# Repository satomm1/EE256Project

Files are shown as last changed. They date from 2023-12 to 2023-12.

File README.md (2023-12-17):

# EE 256 Project --- The Smart Pot
Matthew Sato <br />
satomm@stanford.edu <br />
Autumn 2023

This repository contains three folders: [`electrical`](electrical), [`software`](software), and [`docs`](docs) which contain all the project deliverables for this project. The project summary with my perspectives on this project is located at the [bottom of this page](#project-summary).

## The Smart Pot
The smart pot is designed as a completely autonomous plant pot that gives you the ability to be a plant parent without the trouble of remembering to water it on a regular basis. It gives water to the plant when it actually is thirsty. Now you can travel without being worried about watering your plant!

### Features of the Smart Pot
- Senses the ambient air temperature and soil moisture of the plant
- Automatically pumps water into pot when soil moisture drops too low
- Sensor to indicate when the water reservoir is low
- Display to show the temperature
- Ability to change temperature units, activate pump manually, and change the threshold at which the pump is activated
- Serial desktop interface and web-based HTML interface
- The features are fully integrated across the board, serial interface, and webpage. Any update in setting in one of these interfaces results in the corresponding update to the other interfaces.


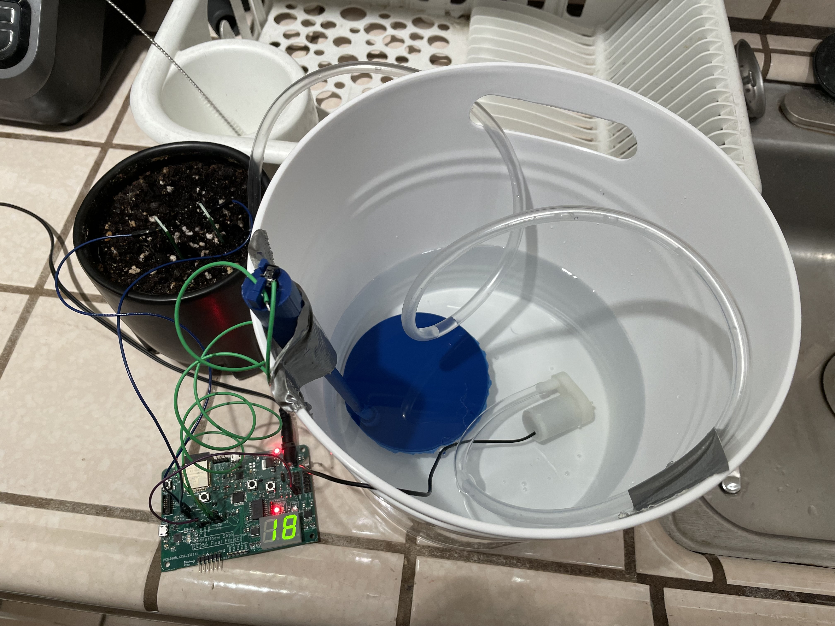
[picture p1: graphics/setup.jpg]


### Implementation Details of the Smart Pot
- The Smart Pot is built on a PCB and is under the control of a PIC32 microcontroller
- Temperature sensing is performed via a thermistor
- Soil moisture sensing is performed with two probes manufuctured on a PCB
- The water tank sensor is a limit switch which is activated by a plunger when the water is too low
- The WiFi capability is added with an ESP32 and communicates with the PIC32 via SPI
- Powered with a 5 V DC barrel jack
- A 7 segment display implemented with shift registers and SPI
- 2x UART to USB bridges to allow serial communication with a desktop machine

### More Details
To learn more about the product, visit the following folders:
1. [`docs`](docs/): contains the product brief, product requirements, product design document, bill of materials, bringup plan, and unit tests document
2. [`electrical`](electrical/): contains the detailed KiCad schematic and PCB layout
3. [`software`](software/): contains the software for the Smart Pot

### Instruction Manual
The fully functional board appears as follows:
The unit with components labeled

A. The power supply barrel jack. Insert 5V DC only. <br />
B. The display for the product. Can show temperature in F/C, or the soil moisture percentage <br />
C. The function button. Short pressing once will switch the watering frequency to between the low threshold and the high threshold. A long press will activate the pump. A double press activates selection mode. In selection mode, you can click the button to select Fahrenheit units, Celsius Units, or Soil Moisture to display. After 5 seconds of inactivity in selection mode, the display will show the desired quantity.<br />
D. The serial output. Connect this USB-Micro port to your computer and see the current data using a baud rate of 115200. I recommend TeraTerm, and the proper driver for a CP2102 USB-UART driver must be installed on your machine. The output looks like the following:
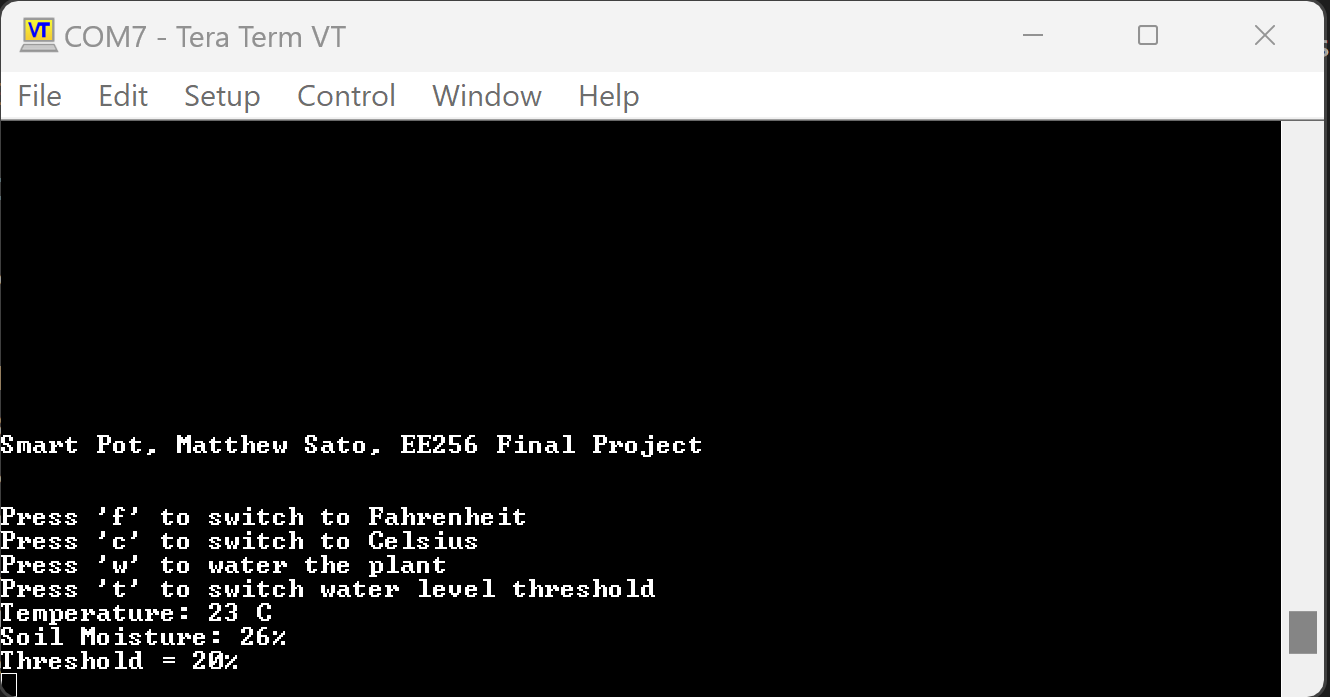
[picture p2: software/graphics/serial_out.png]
An image of the serial out interface

E. These two LEDs indicate if the low soil moisture threshold or high soil moisture threshold are selected.<br />
F. This blue LED indicates when your water tank is low:

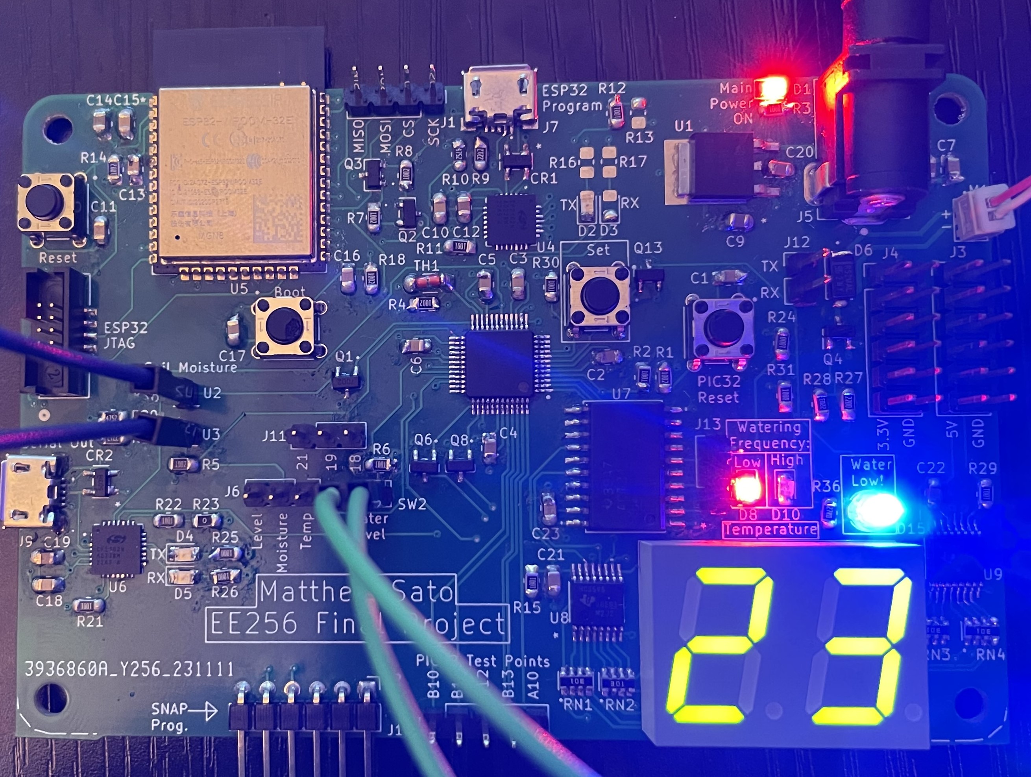
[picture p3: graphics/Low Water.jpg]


G. The port for the pump<br />
H. The ports for the soil moisture probes. The probes should be placed in the pot approximately one inch apart:

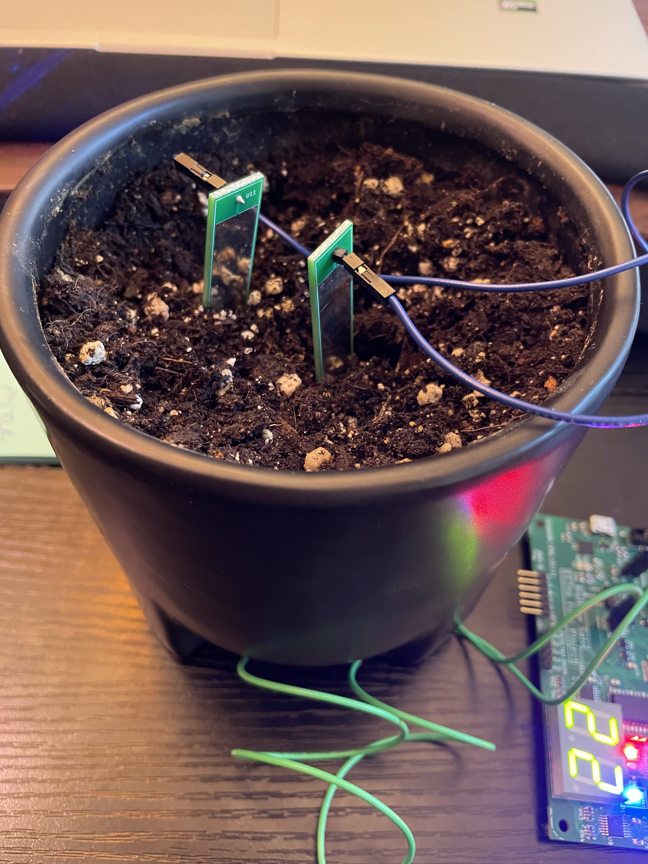
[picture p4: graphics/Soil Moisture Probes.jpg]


I. The ports for the water tank level sensor. The sensor can be mounted as follows:

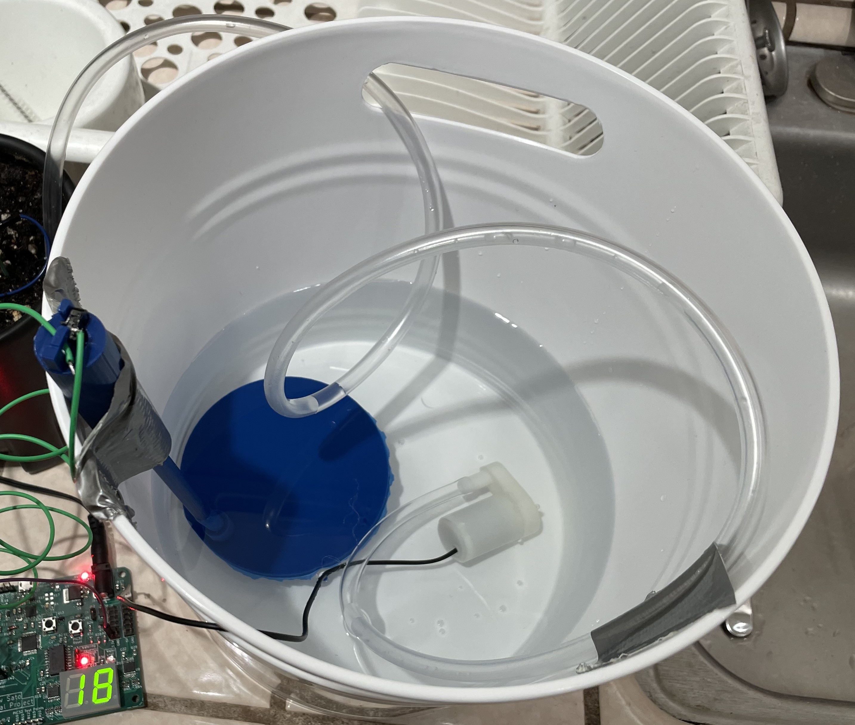
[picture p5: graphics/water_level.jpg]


The unit should be turned on for approximately 5 minutes before a reliable temperature can be maintained.

All data can also be viewed on a web browser:
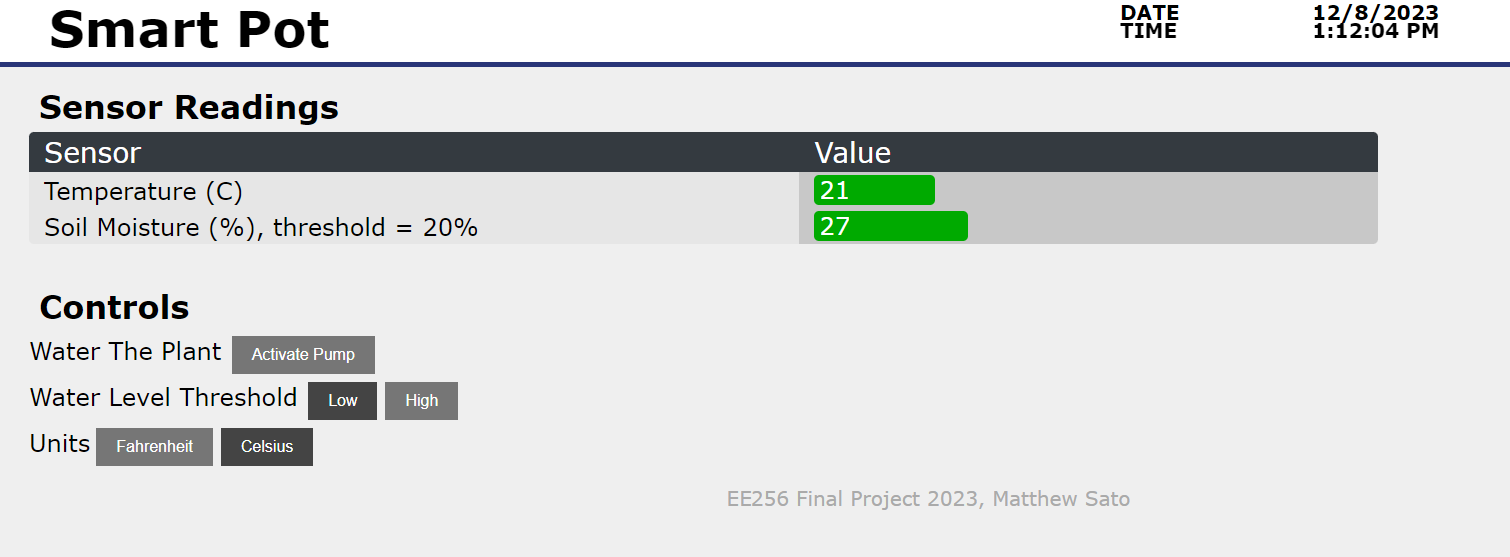
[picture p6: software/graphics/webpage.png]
An image of the webpage


# Project Summary
- In retrospect, why you found this project compelling and was the scope of the project comfortable.
    - I liked that this project allowed us to design a product from start to finish. Going through the design process and how this influences the eventual circuit and PCB design was very informative.
    - I thought the scope of the project was fine, just a little more time at the end would have been nice.
- What were the areas that you learned the most.
    - I learned how to design a circuit from start to finish, including choice of parts. Selecting a part from DigiKey can be daunting, but this project helped me learn how to do this.
    - I also learned a lot from the board bringup --- how to test if things are working, and how to fix poorly soldered joints with a heat gun.
- What are you proud of about the project.
    - After taking ME218, I felt confident about my ability to program a microcontroller to do useful tasks. I am proud that I was able to transfer the skills to the PCB using a slightly different microcontroller and now feel like my capabilities are much larger than before.
- What might you do differently.
    - I would have not used any QFN packages in my design --- these are hard to solder!
    - I would have spent more time doing floor planning in the PCB design before routing the copper.
- Now that you know how to build a PCB based system, what might you want to attempt next?
    - I plan to use my PCB knowledge to design PCBs for my research project(s), including the design of a low-level controller for a mobile robot.

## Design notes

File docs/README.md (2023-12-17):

# Documentation

This folder contains the documentation for the Smart Pot:
- Product Brief
- Product Requirements
- Product Design Document
- Bill of Materials
- Bringup Plan
- Unit Tests Plan

The entire product costs ~$54

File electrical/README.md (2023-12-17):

# Electrical Design

This folder contains the electrical schematic and PCB layout of the project. The project is available as a KiCad file.

My board produces the soil moisture probes on the PCB. These are cut from the PCB after production via a notcher.

3D View of PCB:
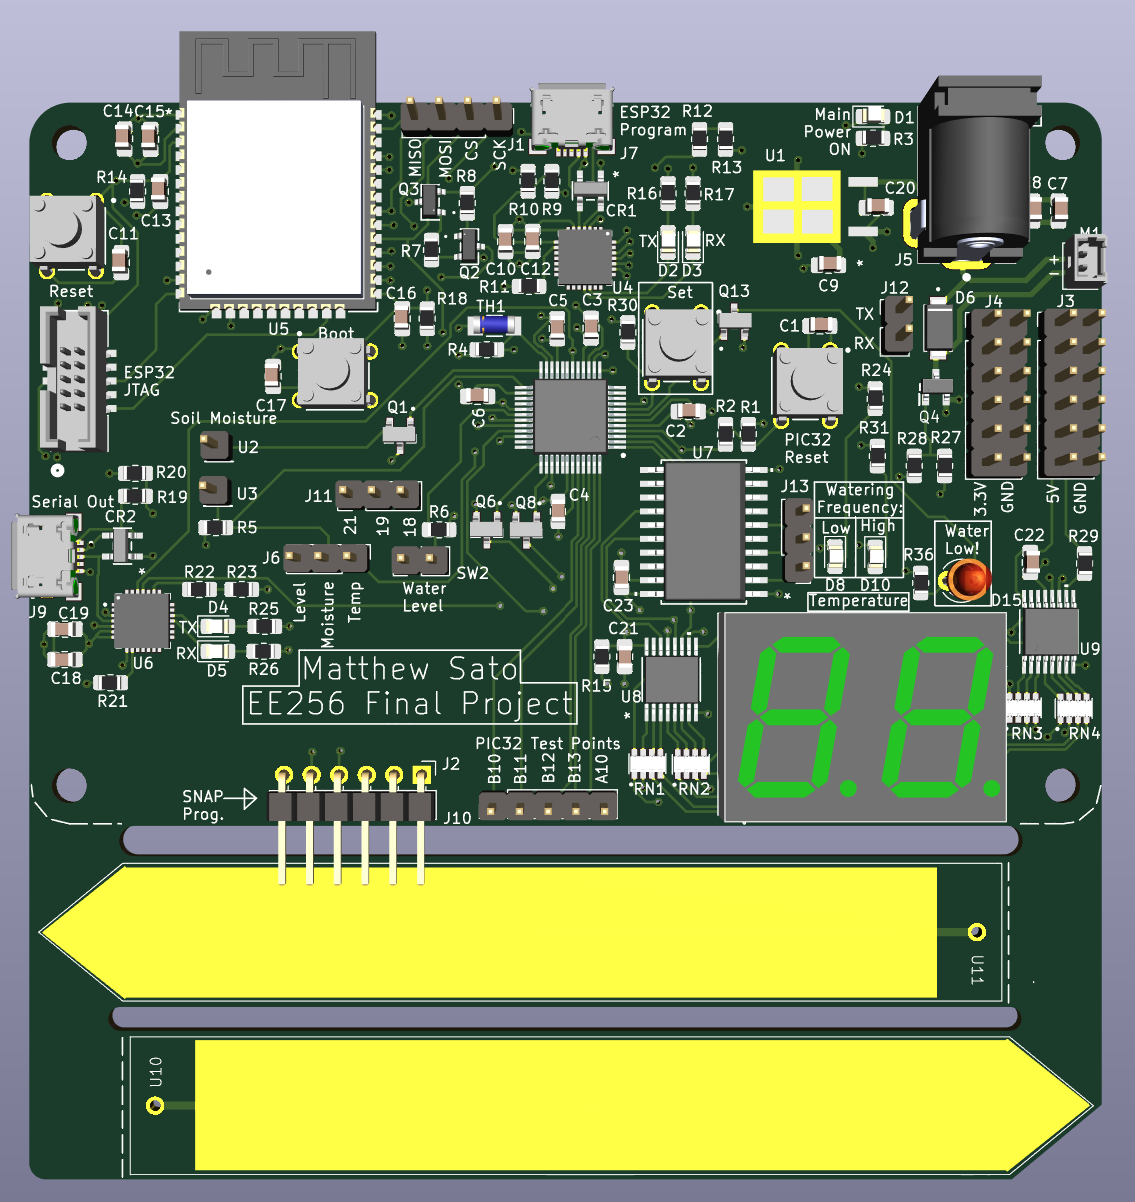
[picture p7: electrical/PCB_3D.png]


PCB Layout:
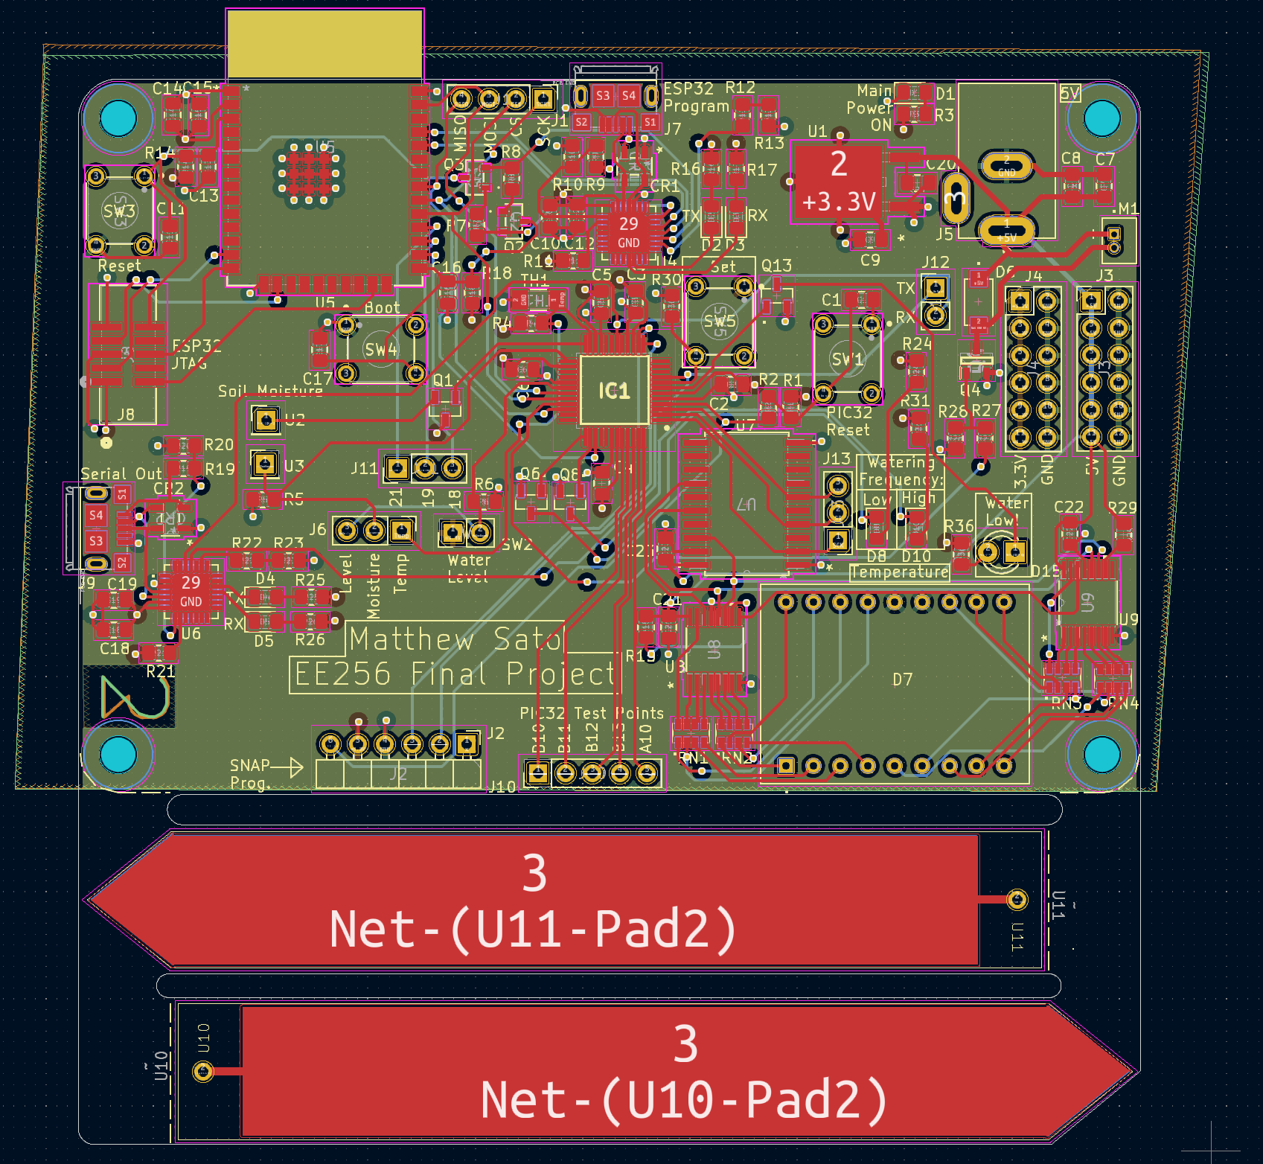
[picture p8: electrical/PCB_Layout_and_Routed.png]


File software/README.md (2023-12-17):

# Software

This repo contains software for the PIC32 main microcontroller, as well as the ESP32 WiFi coprocessor.

## PIC32

The PIC32 is programmed with MPLAB X in C. An event driven framework is used. State machines are used to manage the different components of the board:
- USB Serial Output
- 7 Segment Display
- Pump
- Soil Moisture
- Temperature
- User Button Debouncer
- Water Button Debouncer
- WiFi communications

## ESP32
The ESP32 is programmed with the Arduino IDE. The ESP32 acts as a WiFi server which can update HTML webpages by sending XML messages with updated data.

Webpage Monitoring:


Serial Out Monitoring:


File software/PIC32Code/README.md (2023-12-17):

# PIC32Framework
Event Driven Framework for the PIC32

Original author: J. Ed Carryer for the ME218 course series at Stanford University.

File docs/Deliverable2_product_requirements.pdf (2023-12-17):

Matthew Sato | Product Requirements Document | 10/12/2023

1

Smart Pot Automatic Plant Watering System

General Requirements

Sensing:

1. The Smart Pot shall be capable of sensing the moisture of soil with probes that can be inserted into soil
2. The Smart Pot shall be capable of sensing the ambient air temperature
3. The Smart Pot shall be capable of sensing the water level of the reservoir

Watering:

1. The Smart Pot shall contain a submersible pump that can be moved into any water reservoir
2. The Smart Pot shall transport water from the reservoir to the plant using a pump and plastic tubing
3. The Smart Pot shall initiate watering when the soil moisture reaches a threshold
4. The Smart Pot shall allow the user to select the watering frequency (at which soil moisture levels the watering should be activated)
5. The Smart Pot shall allow the user to manually activate the pump

User Interfaces

Display System:

1. The Smart Pot shall display the ambient air temperature and soil moisture level on a display
2. The Smart Pot shall update the display at least once per minute
3. The Smart Pot shall display a message when the water level has dropped below a threshold to remind the user to refill the reservoir
4. The Smart Pot shall provide an indication of how often the plant will be watered

User Interactions:

1. The Smart Pot shall provide an interface to set the threshold for watering, allow manual watering, and change the temperature units

Communications

WiFi:

1. The Smart Pot shall be capable of functioning as a WiFi server on 802.11 b/g/n wireless networks
2. The Smart Pot shall publish a stream of the soil moisture and air temperature to a HTML webpage for viewing by a user
3. The Smart Pot shall allow the user to log the data via the serial interface

Power

1. The Smart Pot shall be powered by a 5V DC barrel jack supplied by an AC power adapter
2. The AC power adapter shall provide a voltage of 5 V DC using a mains voltage of 100 VAC to 240 VAC with line frequency of 50-60 Hz

Matthew Sato | Product Requirements Document | 10/12/2023

2

Environmental

1. The Smart Pot shall operate at temperatures of 0-40°C
2. The Smart Pot electronics shall be ingress protected to a level of IP24

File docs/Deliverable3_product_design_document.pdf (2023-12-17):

Matthew Sato | Product Design Document | 10/24/2023
| Smart Pot Automatic Plant Watering System

Block Diagram for the System:

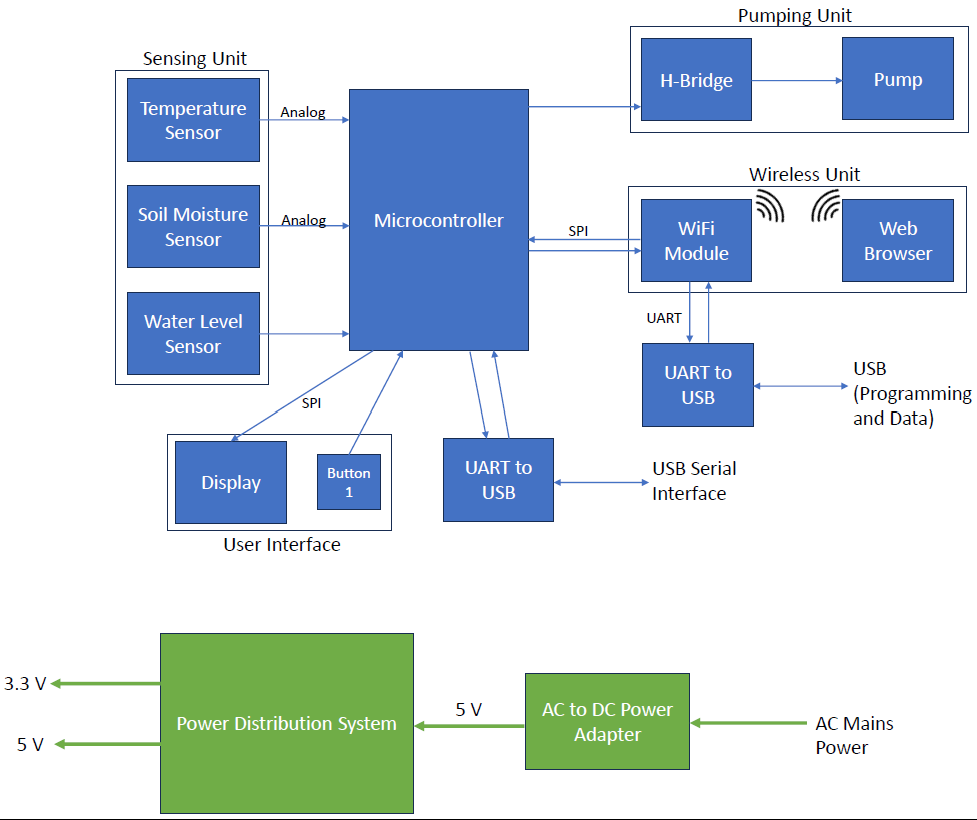
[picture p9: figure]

More detailed descriptions of each block are provided in the following pages.

- Inputs
- a 3.3 V DC power supply
- Outputs
- Analog signal indicating temperature
- Function
- Senses the temperature of the air and communicates these values via an analog signal

Soil Moisture Sensor:

- Inputs
- A 3.3 V DC power supply
- Outputs
- An analog signal between 0 and 3.3 V
- Function
- Senses the moisture of the soil and outputs as an analog voltage
- Inputs
- A 3.3 V DC power supply
- Outputs
- A digital signal indicating if the water level is low
- Function
- Senses if the water level in the reservoir is too low and needs to be refilled

## Temperature Sensor

## Soil Moisture Sensor

## Water Level Sensor

Analog

Analog

- Inputs
- An up to 5 V DC voltage
- SPI CLK, CS, and Data In digital lines
- Outputs
- none
- Function
- Displays relevant information and data on a screen
- Inputs
- 3.3 V DC
- Outputs
- A digital signal indicating if the button has been pressed
- Function
- Provides a signal for button pushes
- Inputs
- 3.3 V DC
- SPI CLK, CS, and Data In digital signal
- UART Data In
- RF signal compliant with 802.11 a/g/n
- Outputs
- SPI Data Out digital signal
- UART Data out
- RF signal compliant with 802.11 a/g/n
- USB-C port
- Function

## Display

Button
1

## WiFi Module

### SPI

SPI | UART

- Receives a message over SPI and publishes the message via WiFi; also repeats the received data from the SPI line through a UART line
- Inputs
- 3.3 V DC
- UART Data in
- Outputs
- UART Data out
- USB D+/D-
- Function
- Translates the UART message to USB and vice versa. The USB lines can be sent to interface with a computer. Ultimately, this will be the interface for programming the WiFi module, and will also allow the data to be sent to a computer serially.
- Inputs
- 3.3 V DC and 5 V DC
- 3.3V digital input to control the pump speed
- Outputs
- A 5 V pulse width modulated signal going to the pump
- Function
- Produces a driving voltage for the pump
- Inputs
- UART RX and USB D+/-
- 3.3 V DC
- Outputs
- UART TX
- Function

## UART to USB

H-Bridge | Pump

## UART to USB

UART | USB D+/D-

## USB Serial Interface

### UART

- Provides serial communication to computer terminal for microcontroller
- Inputs
- 3.3V DC
- 1x analog signal
- 4x digital signals
- Outputs
- 1x PWM signal
- Serial Communications
- 1x UART
- 2x SPI
- Function
- Acts as the central device that interprets sensor signals and controls the entire device

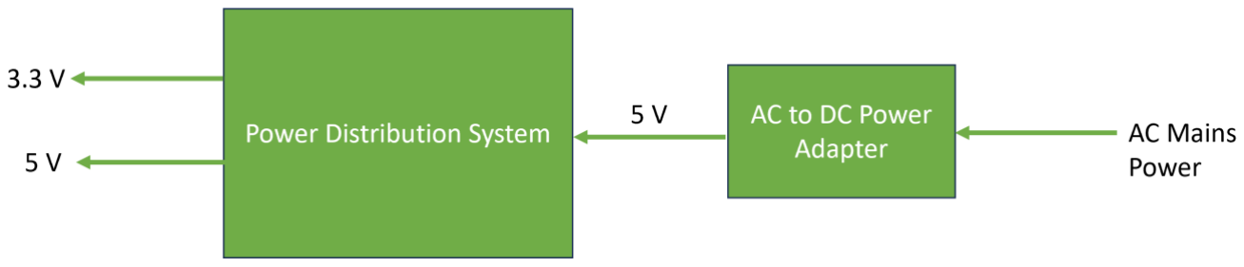
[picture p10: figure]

- Inputs
- An AC power source of 100 VAC to 240 VAC with line frequency of 50-60 Hz
- Outputs
- 3.3 V DC
- 5 V DC

## Microcontroller

- Function
- Converts the AC mains voltage to a logic level 3.3 V DC voltage and a 5 V DC voltage

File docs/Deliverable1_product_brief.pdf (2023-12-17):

Dev Savla, Matthew Sato | EE 256 Product Brief | 9/26/2023
| Smart Pot - Automatic Plant Watering Pot

Have you ever wondered about owning a potted plant in your home but you worry about taking care of it? Your worry ends with this Smart Pot. Say goodbye to overwatering and underwatering your plant with this innovative product. It’s where technology meets nature. Your plant will thank you!

Features:

- Automatic watering of the plant based on the plant’s needs by sensing the soil moisture level
- Also works as a weather station by showing the ambient temperature
- All data viewable via a web interface or serial interface
- Can set your desired watering frequency with a button and can water on demand
- Alert to warn when the water reservoir is low
- Healthy and thriving plants with minimal effort
- All for under $100

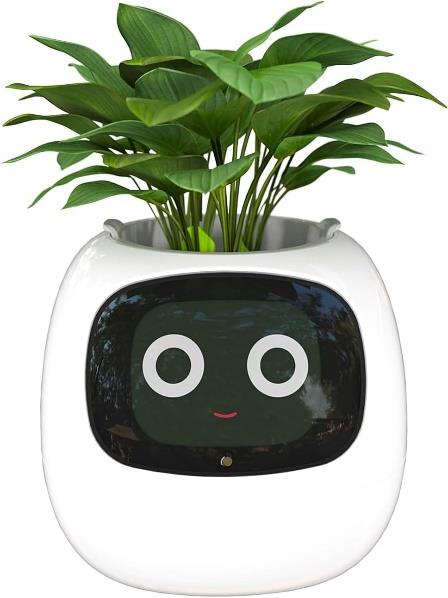
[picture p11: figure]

What makes this product special?

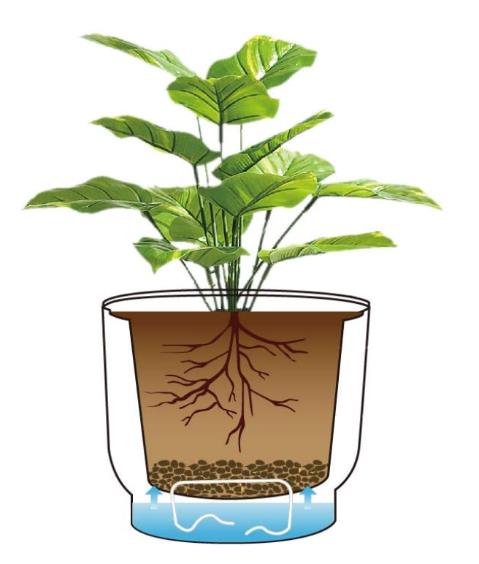
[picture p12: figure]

It’s a completely autonomous plant pot that gives you the ability to be a plant parent without the trouble of remembering to water it on a regular basis. It gives water to the plant when it actually is thirsty. Now you can travel without being worried about watering your plant!

Dev Savla, Matthew Sato | EE 256 Product Brief | 9/26/2023

Requirements (and how we meet them):

- A microcontroller
- Use a microcontroller to read sensor data and send messages via the Wi-Fi module
- At least two sensors
- Soil Moisture Sensor
- Air Temperature Sensor
- Humidity Sensor
- Ability to log sensor data
- Microcontroller can store data and send logged data via Wi-Fi module
- At least two communication modalities
- Wi-Fi Module
- SPI/I2C
- A power system
- 5V rechargeable battery with voltage regulator to reduce power to 3.3 V
- No more than two purchased modules
- Wi-Fi Module
- LCD Display Screen
- Fits on a 99 mm x 99 mm PCB
- A submersible motor pump to deliver the water
- A display screen to display the relevant information

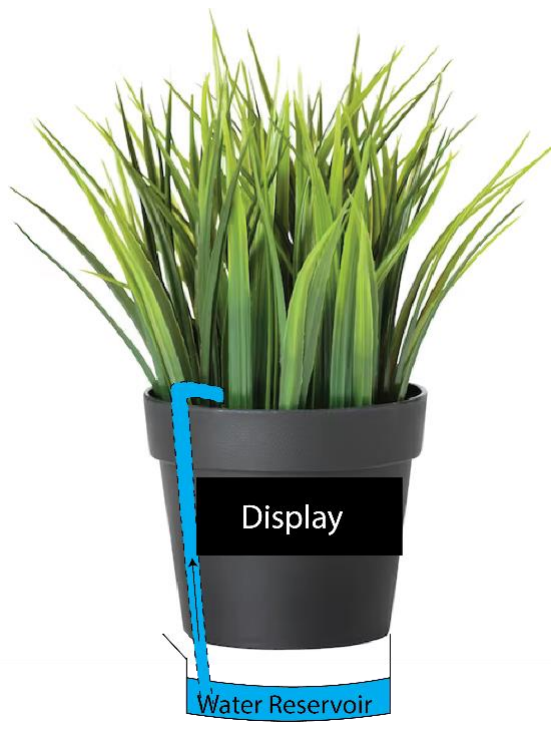
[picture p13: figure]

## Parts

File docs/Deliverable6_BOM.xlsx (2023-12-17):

References | Value | Footprint | Quantity | Supplier | P/N | Cost/Unit | Total Cost
C1, C2, C3, C4, C5, C6, C7, C10, C11, C13, C15, C16, C17, C18, C21, C22, C23 | 0.1 uF | C_0805_2012Metric_Pad1.18x1.45mm_HandSolder | 17 | DigiKey | 1276-1003-1-ND | 0.042 | $0.71
C8, C20 | 10 uF | C_0805_2012Metric_Pad1.18x1.45mm_HandSolder | 2 | DigiKey | 1276-1096-1-ND | 0.1 | $0.20
C9, C14 | 22 uF | C_0805_2012Metric_Pad1.18x1.45mm_HandSolder | 2 | DigiKey | 1276-1100-1-ND | 0.13 | $0.26
C12, C19 | 4.7 uF | C_0805_2012Metric_Pad1.18x1.45mm_HandSolder | 2 | DigiKey | 1276-1244-1-ND | 0.1 | $0.20
R2, R6, R11, R12, R15, R21, R22, R29, R30 | 1k | R_0805_2012Metric_Pad1.20x1.40mm_HandSolder | 9 | DigiKey | RMCF0805FT1K00CT-ND | 0.02 | $0.18
R1, R4, R5, R7, R8, R14, R18 | 10k | R_0805_2012Metric_Pad1.20x1.40mm_HandSolder | 7 | DigiKey | RMCF0805FT10K0CT-ND | 0.02 | $0.14
R3, R16, R17, R24, R25, R26, R31 | 100R | R_0805_2012Metric_Pad1.20x1.40mm_HandSolder | 7 | DigiKey | RMCF0805FT100RCT-ND | 0.02 | $0.14
R9, R19 | 22.1k | R_0805_2012Metric_Pad1.20x1.40mm_HandSolder | 2 | DigiKey | RMCF0805FT22K1CT-ND | 0.02 | $0.04
R10, R20 | 47.5k | R_0805_2012Metric_Pad1.20x1.40mm_HandSolder | 2 | DigiKey | RMCF0805FT47K5CT-ND | 0.02 | $0.04
R13, R23 | 0R | R_0805_2012Metric_Pad1.20x1.40mm_HandSolder | 2 | DigiKey | RMCF0805ZT0R00CT-ND | 0.017 | $0.03
R27 | 220R | R_0805_2012Metric_Pad1.20x1.40mm_HandSolder | 1 | DigiKey | RMCF0805FT220RCT-ND | 0.19 | $0.19
R28 | 220k | R_0805_2012Metric_Pad1.20x1.40mm_HandSolder | 1 | DigiKey | RMCF0805FT220KCT-ND | 0.43 | $0.43
R36 | 27R | R_0805_2012Metric_Pad1.20x1.40mm_HandSolder | 1 | DigiKey | 738-RMCF0805FT27R0CT-ND | 2.76 | $2.76
D1, D2, D3, D4, D5, D8, D10 | LED | LED_0805_2012Metric_Pad1.15x1.40mm_HandSolder | 7 | DigiKey | 732-4984-1-ND | 0.21 | $1.47
D6 | RS2MAL | SODFL5226X100N | 1 | DigiKey | 1801-RS2MALCT-ND | 4.66 | $4.66
D7 | HDSP-523G | LED_HDSP-523G | 1 | DigiKey | 516-1209-5-ND | 0.36 | $0.36
D15 | Water Level Low | LED_D3.0mm | 1 | DigiKey | 732-11401-ND | 0.59 | $0.59
U4, U6 | CP2102N-A02-GQFN28R | CP2102-28__IC_CP2102N-A02-GQFN28R | 2 | DigiKey | 336-5890-1-ND | 2.8 | $5.60
U8, U9 | SN74HCS595PWR | TSSOP16_PW_TEX-M | 2 | DigiKey | 296-SN74HCS595PWRCT-ND | 0.62 | $1.24
U1 | AZ1084CD-3.3TRG1 | TO-252-3_6P6X6P1_DIO-M | 1 | DigiKey | AZ1084CD-3.3TRG1DICT-ND | 0.38 | $0.38
U5 | ESP32-WROOM-32E-N8 | ESP32-WROOM-32E_EXP | 1 | DigiKey | 1965-ESP32-WROOM-32E-N8CT-ND | 0.44 | $0.44
U7 | SN74ACT244DWR | DW20-M | 1 | DigiKey | 296-1070-1-ND | 0.15 | $0.15
SW1, SW3, SW4, SW5 | B3F-1020 | SW_B3F-1000_OMR | 4 | DigiKey | SW402-ND | 0.1 | $0.40
SW2 | Water Level | PinHeader_1x02_P2.54mm_Vertical | 1 | DigiKey | P10865S-ND | 0.86 | $0.86
Q1, Q6, Q8, Q13 | 2N7002 | 2N7002__SOT95P240X111-3N | 4 | DigiKey | 4878-2N7002CT-ND | 0.29 | $1.16
RN1, RN2, RN3, RN4 | CAY16-301J4LF | RESCAF80P320X160X60-8N | 4 | DigiKey | 118-CAY16-301J4LFCT-ND | 4.25 | $17.00
CR1, CR2 | SP0503BAHTG | TVS-SP05_LTF-M | 2 | DigiKey | F2715CT-ND | 0.23 | $0.46
Q2, Q3 | SS8050-G | SS8050-G__TRAN_SS8050-G_CIP-L | 2 | DigiKey | 641-1790-1-ND | 3 | $6.00
IC1 | PIC32MK0128MCA048-I_Y8X | PIC32MK0128MCA048-I_Y8X__QFP50P900X900X120-48M | 1 | DigiKey | 150-PIC32MK0128MCA048-I/Y8X-ND | 1.5 | $1.50
M1 | Water Pump Connector | MOLEX_53047-0210 | 1 | DigiKey | WM1731-ND | 0.44 | $0.44
M1 | Water Pump |  | 1 | DigiKey | 1778-COM3700-ND | 0.85 | $0.85
M1 | Water Pump Tubing |  | 1 | DigiKey | 1528-4545-ND | 0.46 | $0.46
Q4 | FDN335N | FDN335N__SOT95P251X112-3N | 1 | DigiKey | FDN335NCT-ND | 0.25 | $0.25
TH1 | 10k @ 25 C | SM_USS-M | 1 | DigiKey | F11794CT-ND | 0.18 | $0.18
J7, J9 | USB_B_Micro | AMPHENOL_10118193-0001LF | 2 | DigiKey | 609-4616-1-ND | 0.27 | $0.54
J1, J10, J11, J13 | SPI1 Test Point | PinHeader_1x04_P2.54mm_Vertical | 4 | DigiKey | 10129378-910001BLF-ND | 0.61 | $2.44
J2 | Programmer | PinHeader_1x06_P2.54mm_Horizontal | 1 | DigiKey | 2057-PH1RB-06-UA-ND | 0.76 | $0.76
J3, J4 | 5V Supply Points | PinHeader_2x06_P2.54mm_Vertical | 2 | DigiKey | 10129381-912001BLF-ND | 0.1 | $0.20
J5 | Barrel_Jack | CUI_PJ-002A | 1 | DigiKey | CP-002A-ND | 0.1 | $0.10
J8 | 3221-10-0300-00 | JTAG__CONN10_3221-10-0300-00_CNC | 1 | DigiKey | 1175-1735-ND | 0.1 | $0.10
 |  |  |  |  |  | Total Cost: | $53.92

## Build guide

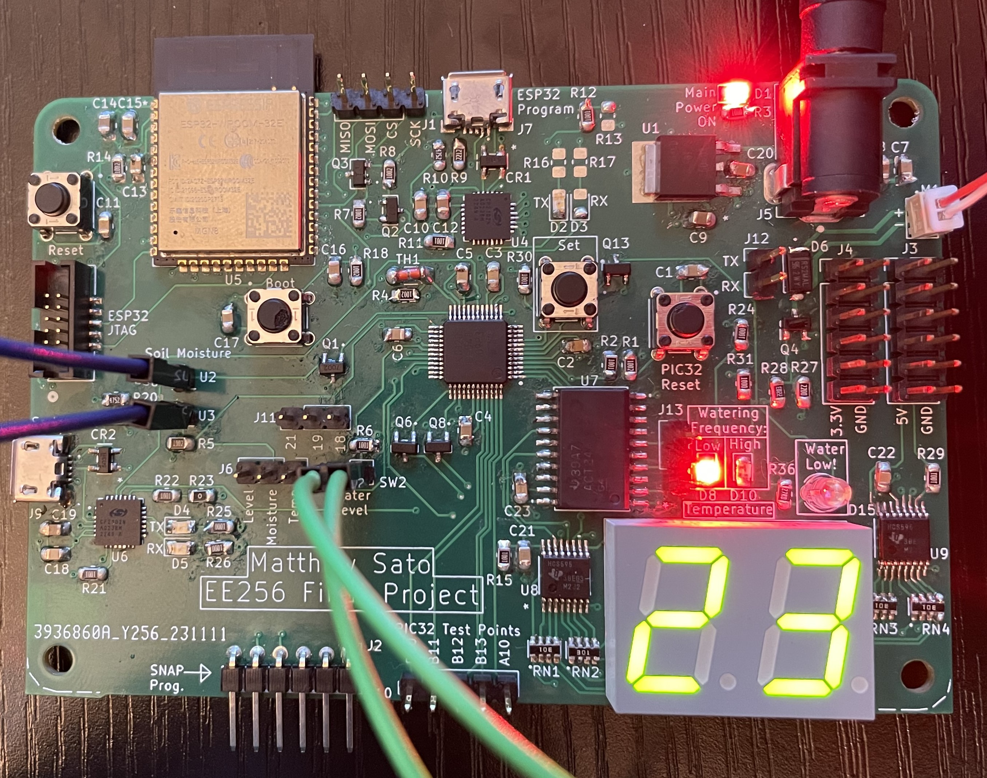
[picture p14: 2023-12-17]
graphics/Normal Operation.jpg

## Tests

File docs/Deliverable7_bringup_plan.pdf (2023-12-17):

Matthew Sato | Unit Test Plan (DVT) | 11/16/2023

1

Smart Pot Automatic Plant Watering System Unit Test Plan

1) Inspect the board visually: ensure everything seems to be as designed.
2) Check for shorts between power and ground.
3) Connect the board to a bench power supply and see that voltage is correct and there is no current.
4) Populate the power system (voltage regulator) and measure voltage on all pads expected to have power.
5) Add the microcontroller, bypass caps, reset button, and ensure there are no solder bridges, and the microcontroller pins are actually connected to the pads we expect (where the sensors, etc. will be soldered).
6) Add the microcontroller programming components and verify the microcontroller can be successfully programmed.
7) Populate the USB-UART bridge section and program the microcontroller to output messages to the USB.
8) Populate the ESP32/WiFi module and ensure connectivity at the place we expect.
9) Add ESP32 programming features (USB-UART and JTAG) and verify programming.
10) Populate the 2x 7-segment display and program the microcontroller to verify functionality.
11) Populate the LED indicators and the push button and program the microcontroller to verify the functionality of these components.
12) Populate the temperature sensor and ensure the microcontroller can detect changes in temperature.
13) Populate the limit switch for water level monitoring and program the microcontroller to detect button events.
14) Populate the soil moisture sensor and program the microcontroller to read the sensor.
15) Populate the pumping system and verify the microcontroller can cause the pump to activate.
16) Integrate (via the microcontroller) to achieve full desired functionality.

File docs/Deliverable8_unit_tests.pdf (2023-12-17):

Matthew Sato | Unit Test Plan (DVT) | 11/16/2023

1

Smart Pot Automatic Plant Watering System Unit Test Plan (DVT)

Power System

- Use an oscilloscope to verify the 3.3 V on the output of the voltage regulator.
- Use an oscilloscope to verify 5V on the 5V pins.

PIC32 Microcontroller

- Use a DMM to verify no solder bridges and connection to all other components.
- Add code and use an oscilloscope to toggle a pin high/low to verify a clock speed of 40 MHz.

USB Serial System

- Use a logic analyzer to verify UART messages are correctly being sent from the PIC32.
- Use a logic analyzer to verify a keystroke from the computer is sent from the USB-UART TX line.
- Verify on a computer terminal that a message sent from the PIC32 is received at the terminal.
- Implement code on the PIC32 to verify keystrokes can be received from the USB-UART bridge via UART (i.e. by repeating the supplied keystroke to the terminal).
- Verify the TX and RX LEDs are correctly lighting up.

Pump System

- Ensure the pump motor is operational before adding to the board.
- Verify the MOSFET is operational by applying 3.3V to the gate.
- Add the pump and manually verify the MOSFET controls the pump by applying 3.3 V to the gate.
- Implement PIC32 code to show control of the pump through the microcontroller.
- If necessary, verify PWM can reduce the flow rate of the pump.

WiFi System

- Verify that the device can be programmed.
- Implement SPI on the PIC32 and ESP32 use test points and a logic analyzer to verify the correct messages are being sent.
- Use the terminal to verify messages are properly being sent and interpreted by the PIC32 and ESP32
- Verify the ESP32 can connect to an access point.

Temperature Display System and User Interaction System

- Ensure 5V signals coming from the 5V buffer.
- Use a logic analyzer to verify SPI messages from the PIC32.
- Using a DMM, verify the outputs of the shift register correspond to the SPI messages.
- Verify the 7-segment displays can display each of the 10 digits.

Temperature Sensor System

- Using a DMM, verify the resistance of the thermistor changes with temperature changes.
- Using an oscilloscope, verify the voltage output of the thermistor circuit changes with temperature changes (and in the correct direction).

Matthew Sato | Unit Test Plan (DVT) | 11/16/2023

2

- Verify the PIC32 ADC reads the same analog value as the oscilloscope.
- Verify the analog values read on the PIC32 are correlated to the temperature.

Soil Moisture Sensor System

- Add the soil moisture probes to the soil, add voltage to one, and verify the output of the other probe varies with moisture.
- Add the MOSFET and verify by applying 3.3V to the gate that the voltage on the probe is on or off when the 3.3V is removed.
- Verify the PIC32 can control turning on the probe via the MOSFET.
- Using an oscilloscope, verify the PIC32 ADC is correctly reading the analog voltage.

Low Water Sensor System

- Verify that the signal is high/low when the button is depressed/released.
- Add PIC32 software to read the status of the signal, provide any necessary debouncing, and verify button presses and button releases can be detected by the PIC32

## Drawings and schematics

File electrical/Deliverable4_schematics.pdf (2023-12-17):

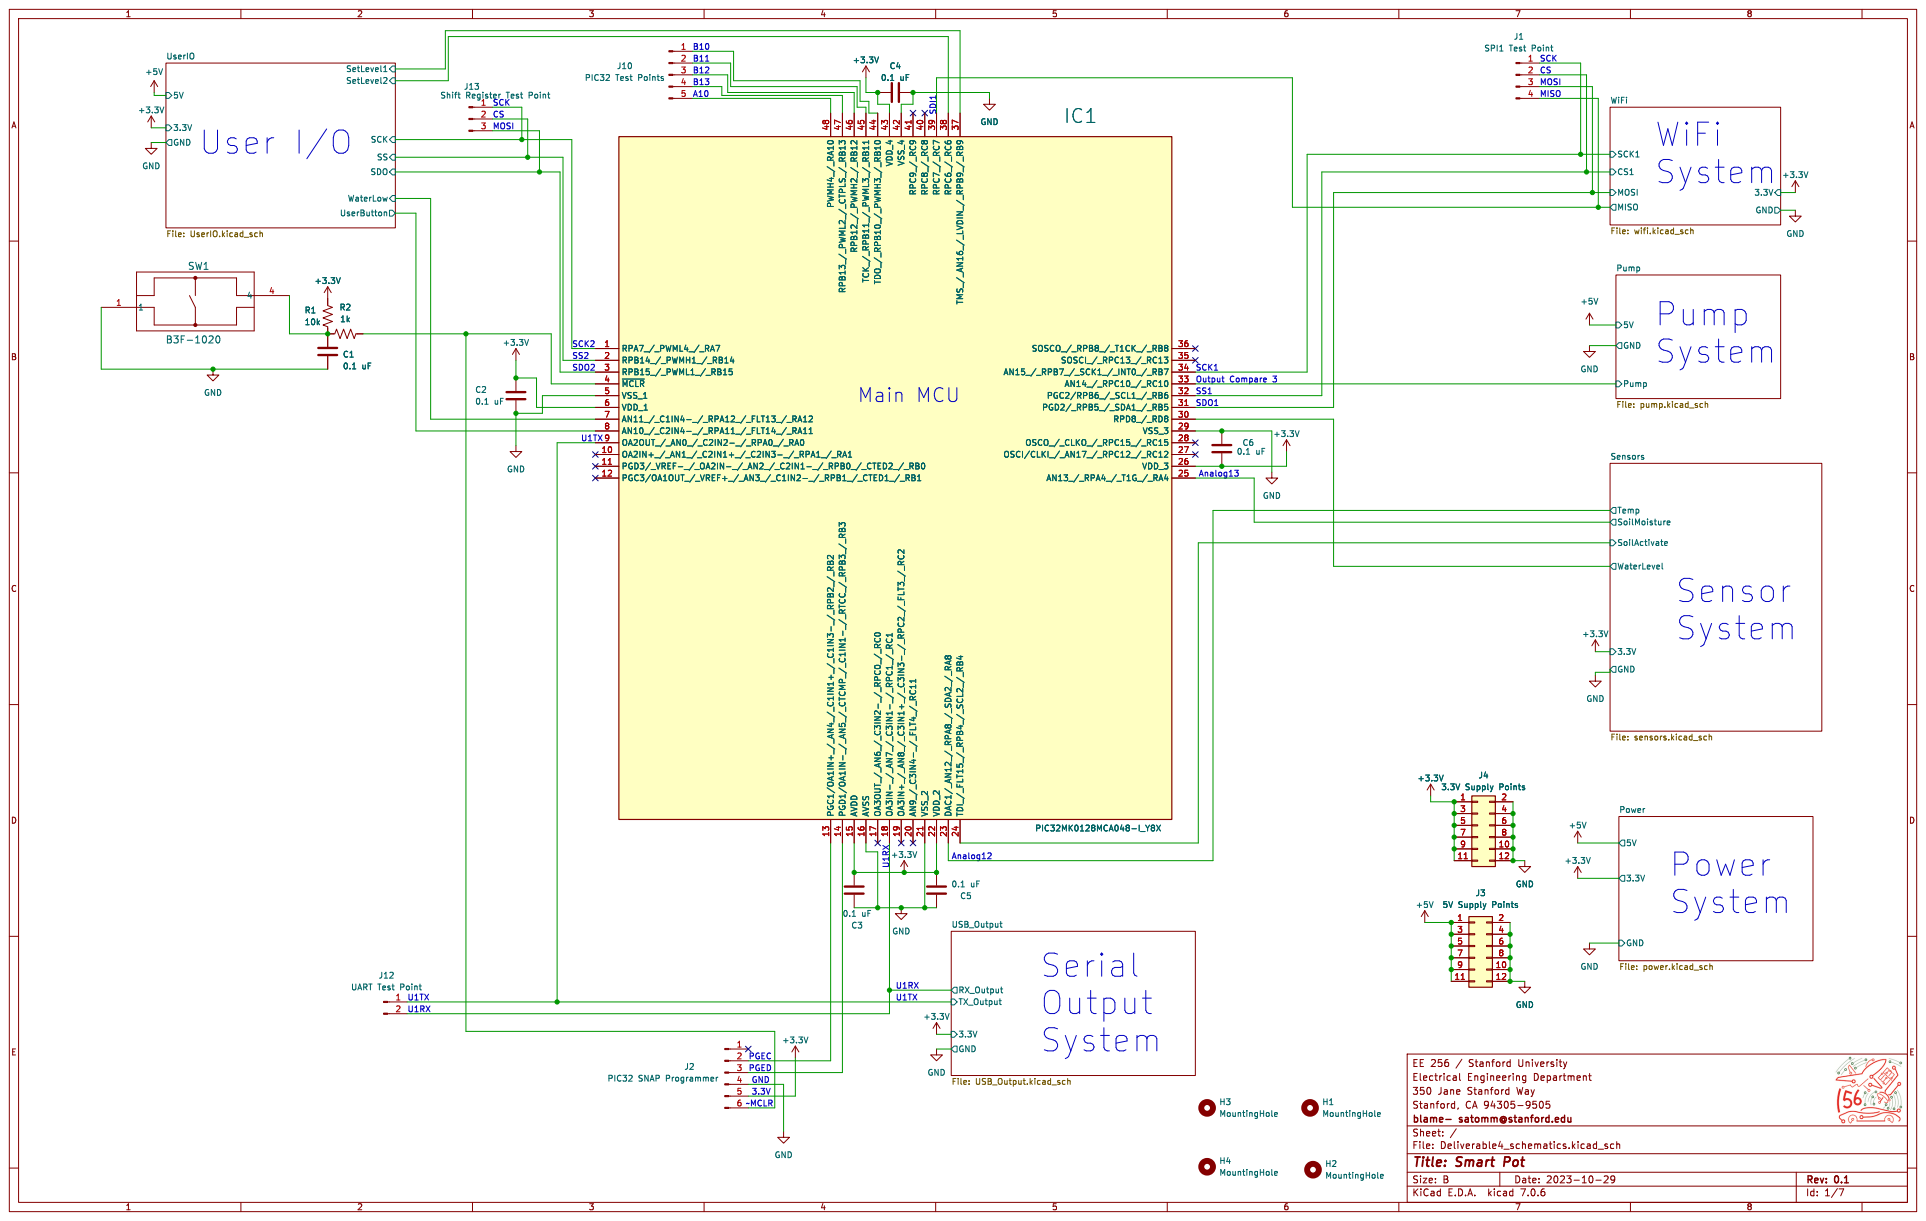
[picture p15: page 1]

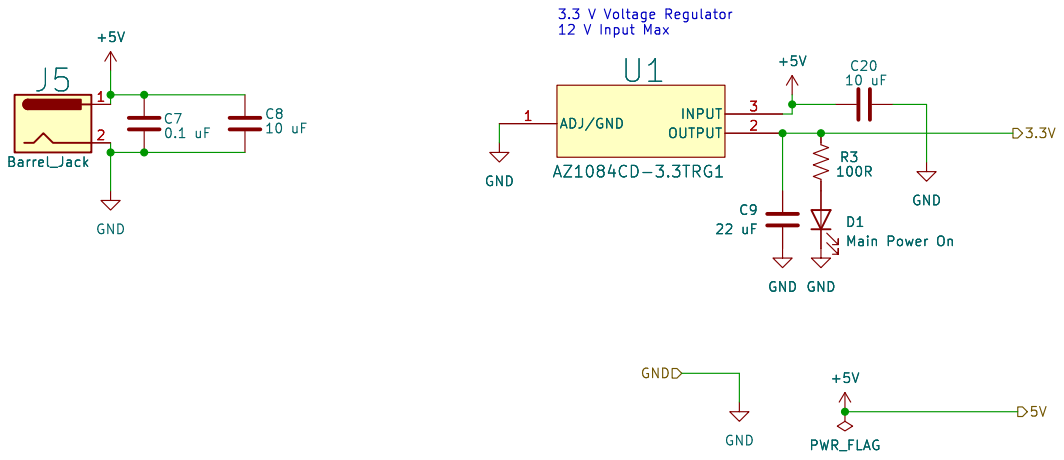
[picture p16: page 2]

D1 Main Power On +5V GND

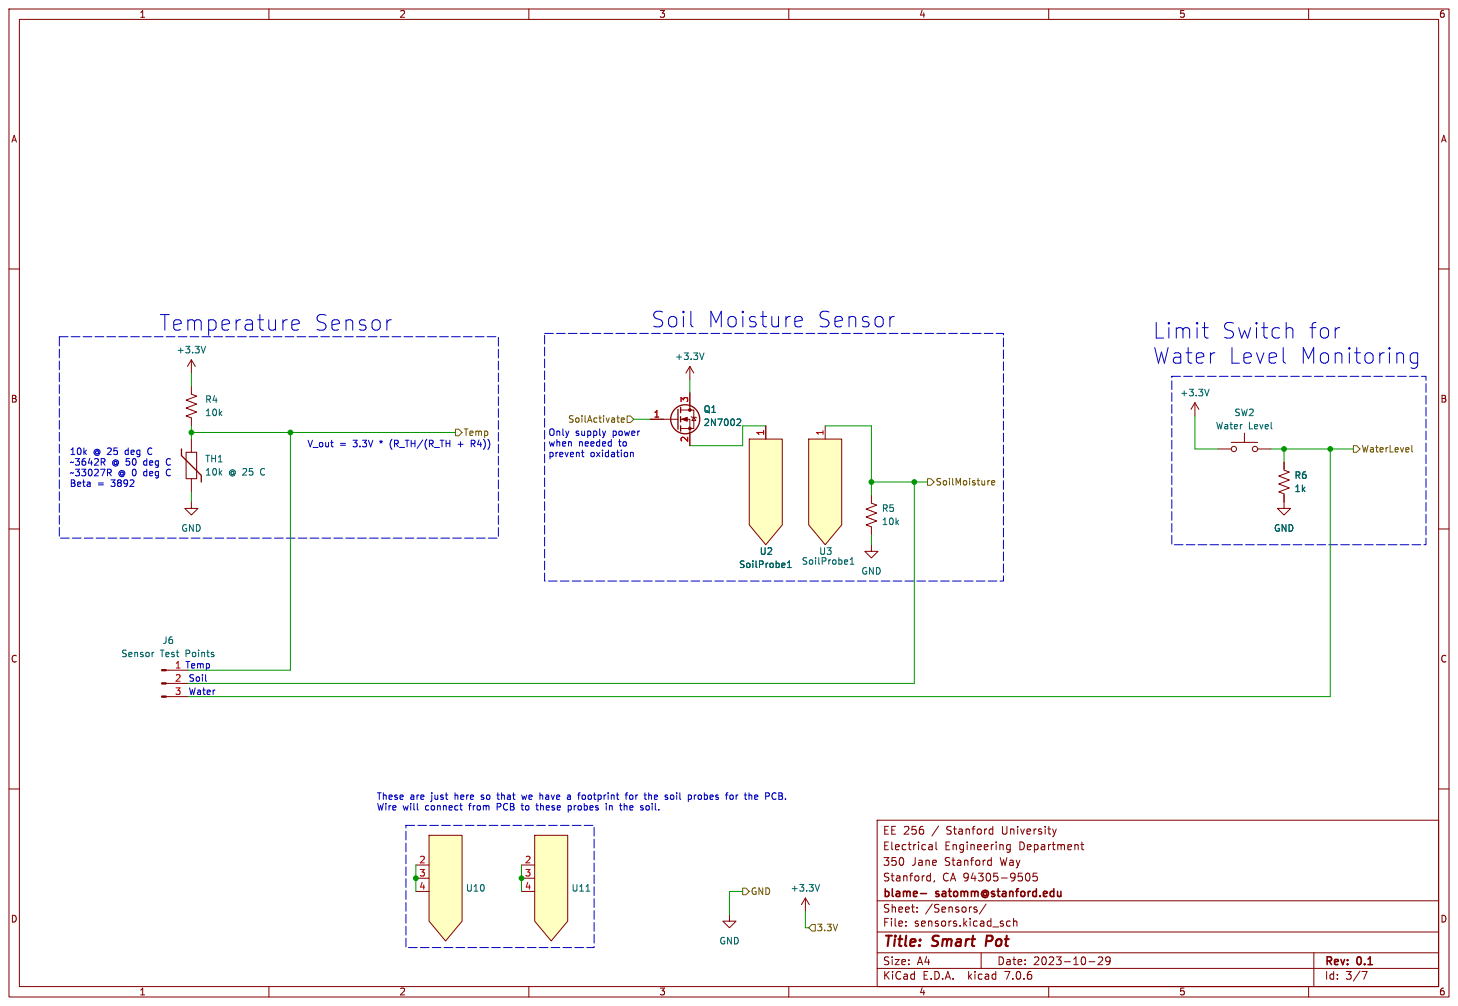
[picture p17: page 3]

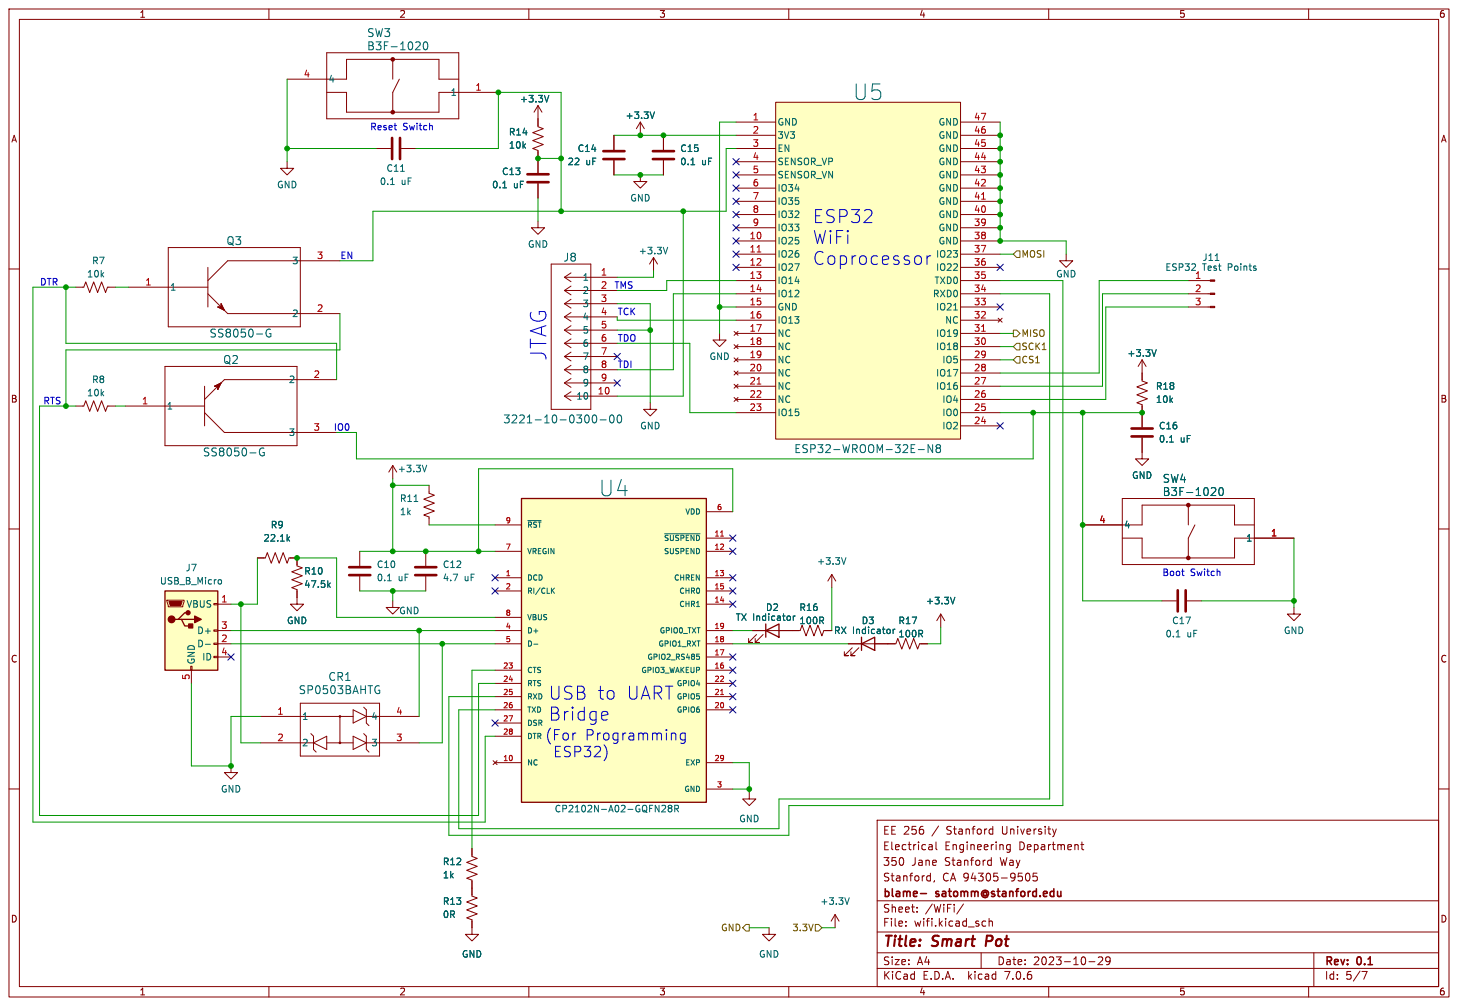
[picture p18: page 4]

Boot Switch USB to UART

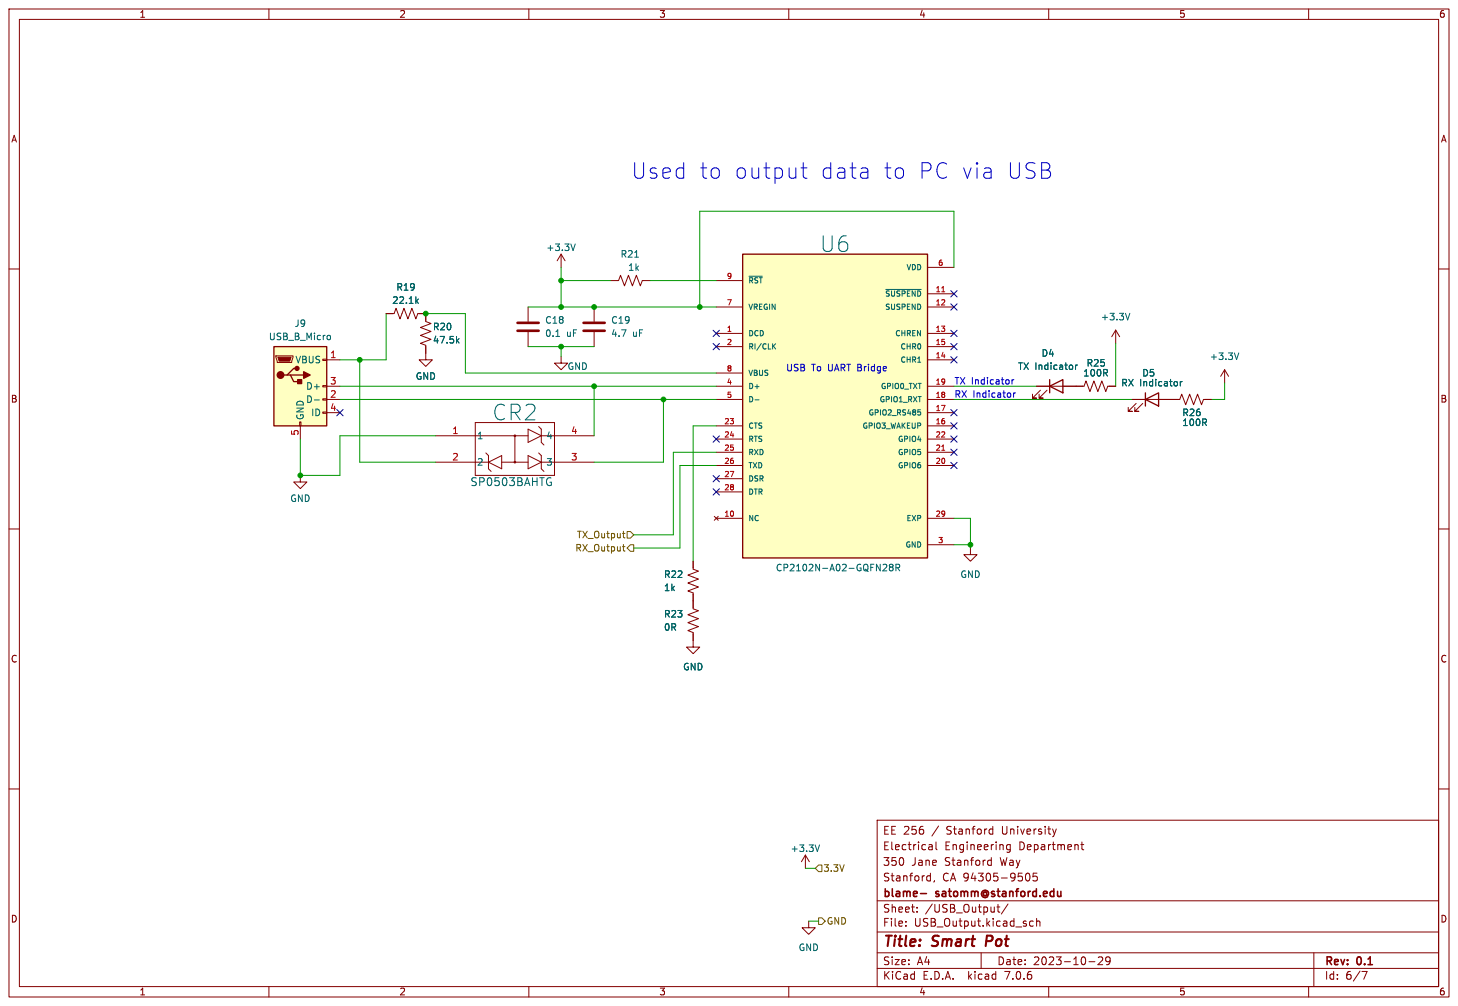
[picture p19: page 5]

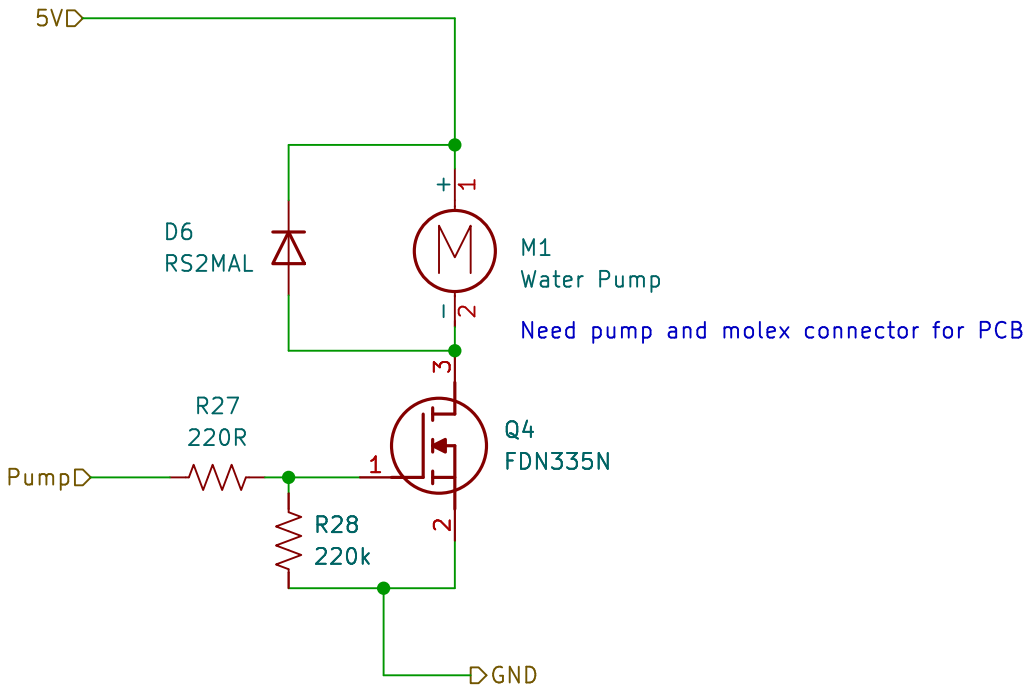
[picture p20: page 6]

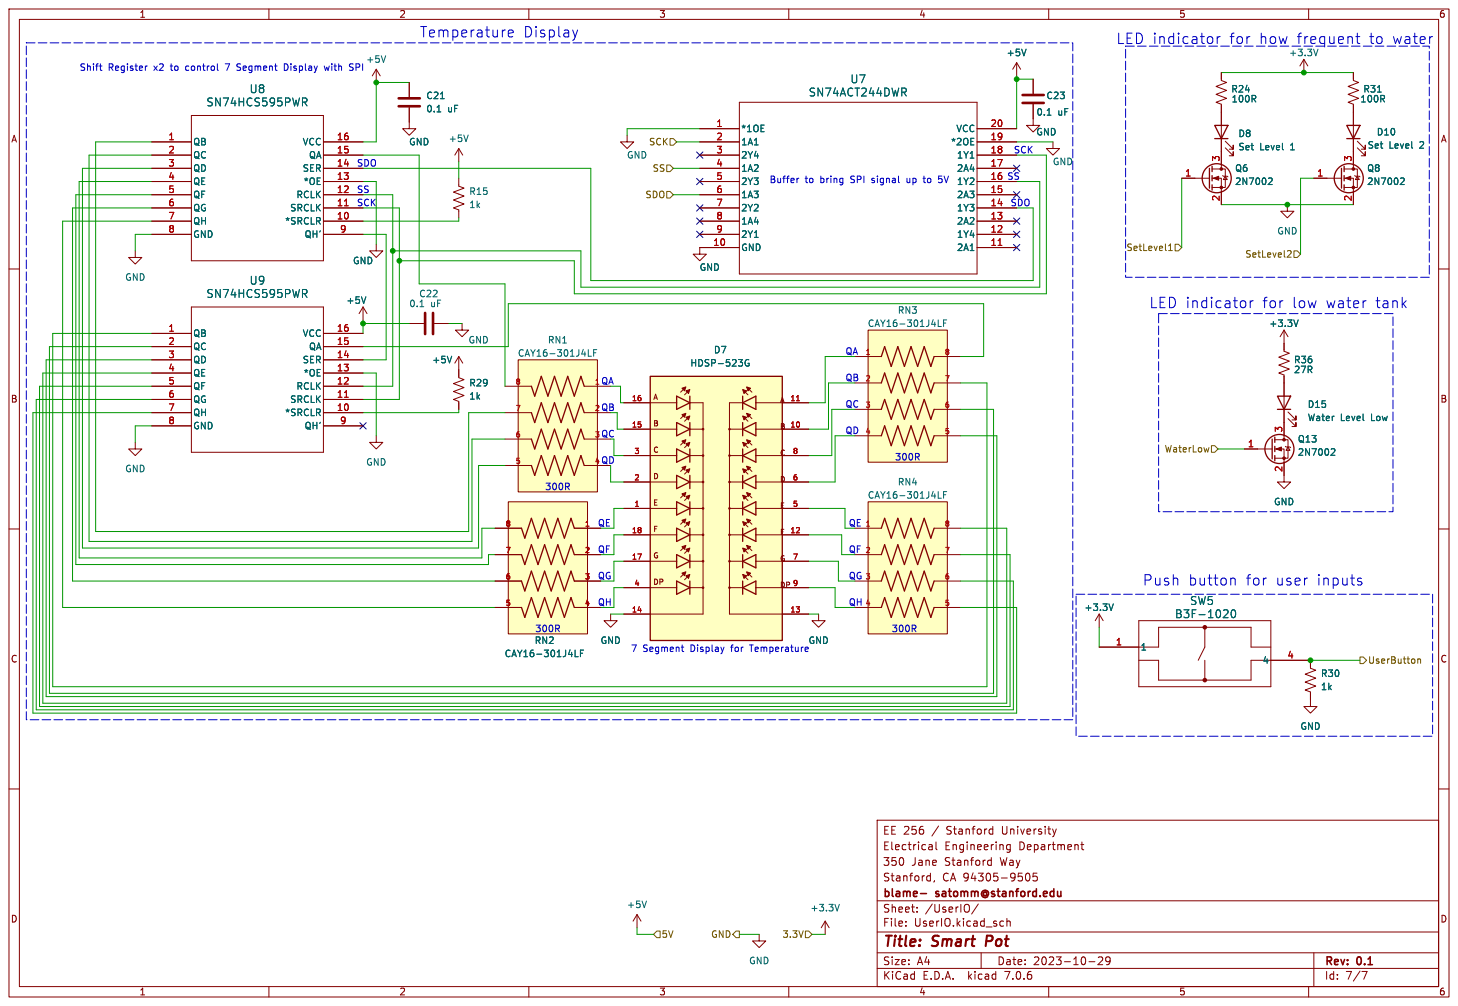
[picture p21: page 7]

7 Segment Display for Temperature

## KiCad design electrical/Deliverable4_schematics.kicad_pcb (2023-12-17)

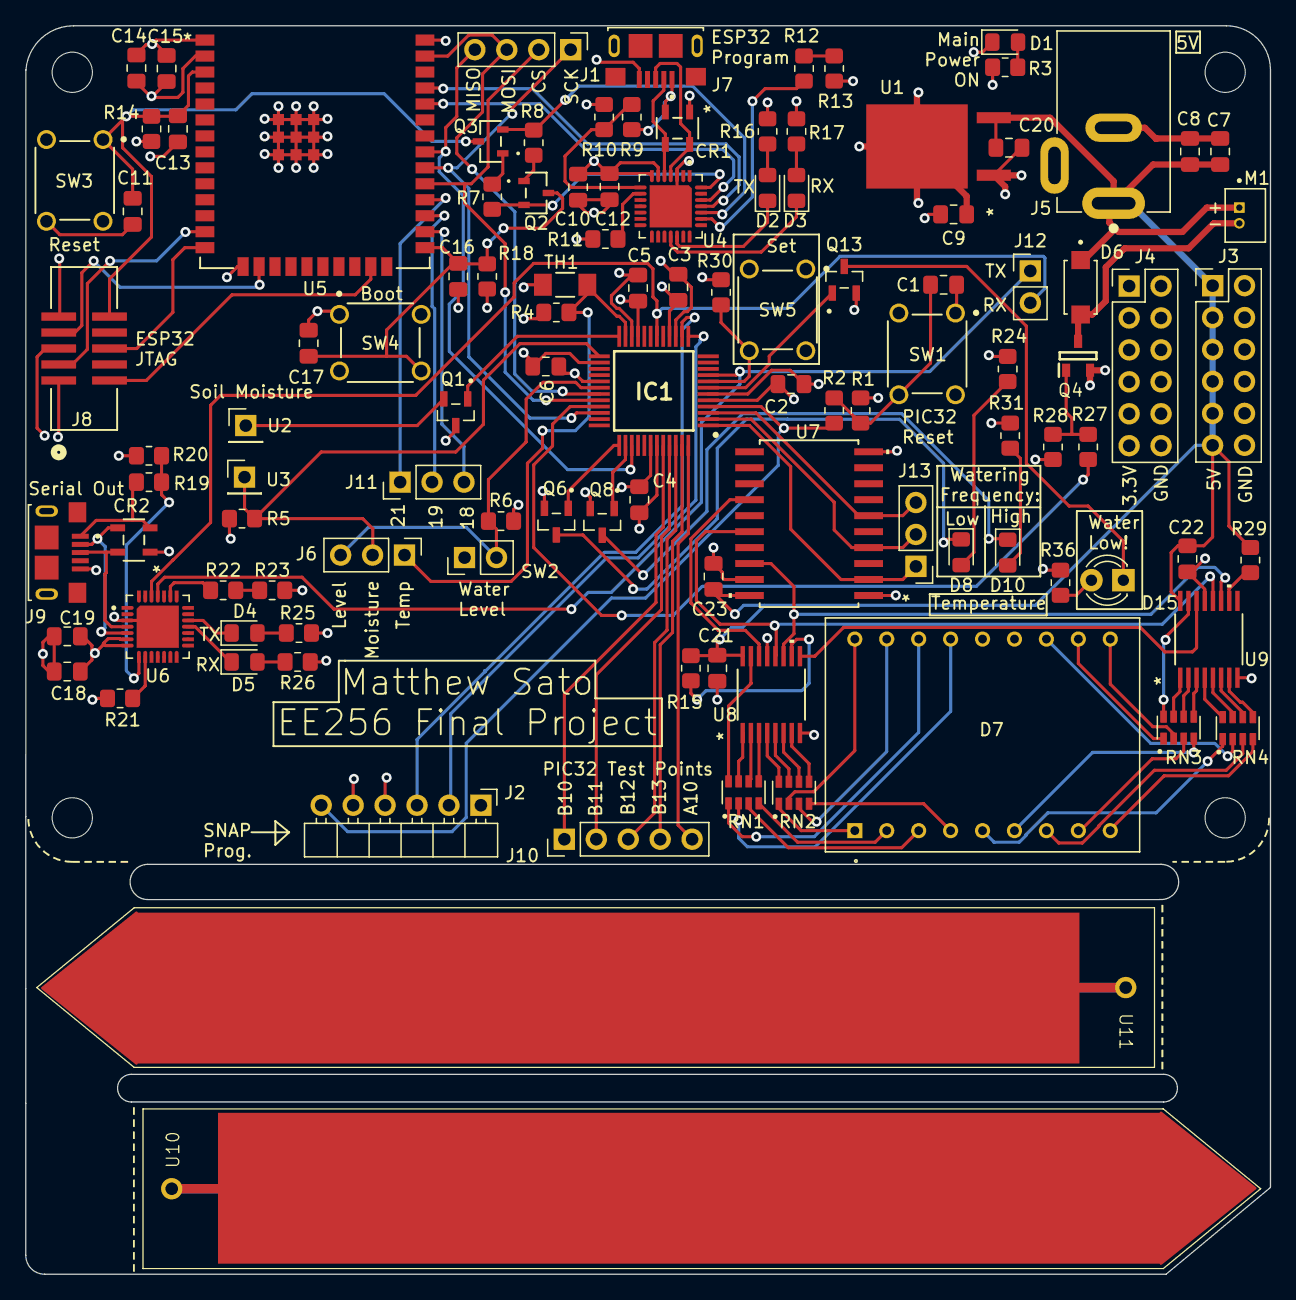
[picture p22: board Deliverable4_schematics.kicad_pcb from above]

Board: 4 copper layers, 99.0 x 99.3 mm, 114 parts (0 on the bottom side), 117 nets.

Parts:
C1, C2, C3, C4, C5, C6, C7, C10, C11, C13, C15, C16, C17, C18, C21, C22, C23: 0.1 uF; C_0805_2012Metric_Pad1.18x1.45mm_HandSolder
C8, C20: 10 uF; C_0805_2012Metric_Pad1.18x1.45mm_HandSolder
C9, C14: 22 uF; C_0805_2012Metric_Pad1.18x1.45mm_HandSolder
C12, C19: 4.7 uF; C_0805_2012Metric_Pad1.18x1.45mm_HandSolder
CR1, CR2: SP0503BAHTG; TVS-SP05_LTF-M
D1: Main Power On; LED_0805_2012Metric_Pad1.15x1.40mm_HandSolder
D2, D3: LED; LED_0805_2012Metric_Pad1.15x1.40mm_HandSolder
D4: TX Indicator; LED_0805_2012Metric_Pad1.15x1.40mm_HandSolder
D5: RX Indicator; LED_0805_2012Metric_Pad1.15x1.40mm_HandSolder
D6: RS2MAL; SODFL5226X100N
D7: HDSP-523G; LED_HDSP-523G
D8: Set Level 1; LED_0805_2012Metric_Pad1.15x1.40mm_HandSolder
D10: Set Level 2; LED_0805_2012Metric_Pad1.15x1.40mm_HandSolder
D15: Water Level Low; LED_D3.0mm
H1, H2, H3, H4: MountingHole; MountingHole_3.2mm_M3
IC1: PIC32MK0128MCA048-I_Y8X; PIC32MK0128MCA048-I_Y8X__QFP50P900X900X120-48M
J1: SPI1 Test Point; PinHeader_1x04_P2.54mm_Vertical
J2: Programmer; PinHeader_1x06_P2.54mm_Horizontal
J3: 5V Supply Points; PinHeader_2x06_P2.54mm_Vertical
J4: 3.3V Supply Points; PinHeader_2x06_P2.54mm_Vertical
J5: Barrel_Jack; CUI_PJ-002A
J6: Sensor Test Points; PinHeader_1x03_P2.54mm_Vertical
J7, J9: USB_B_Micro; AMPHENOL_10118193-0001LF
J8: 3221-10-0300-00; JTAG__CONN10_3221-10-0300-00_CNC
J10: PIC32 Test Points; PinHeader_1x05_P2.54mm_Vertical
J11: ESP32 Test Points; PinHeader_1x03_P2.54mm_Vertical
J12: UART Test Point; PinHeader_1x02_P2.54mm_Vertical
J13: Shift Register Test Point; PinHeader_1x03_P2.54mm_Vertical
M1: Water Pump; MOLEX_53047-0210
Q1, Q6, Q8, Q13: 2N7002; 2N7002__SOT95P240X111-3N
Q2, Q3: SS8050-G; SS8050-G__TRAN_SS8050-G_CIP-L
Q4: FDN335N; FDN335N__SOT95P251X112-3N
R1, R4, R5, R7, R8, R14, R18: 10k; R_0805_2012Metric_Pad1.20x1.40mm_HandSolder
R2, R6, R11, R12, R15, R21, R22, R29, R30: 1k; R_0805_2012Metric_Pad1.20x1.40mm_HandSolder
R3, R16, R17, R24, R25, R26, R31: 100R; R_0805_2012Metric_Pad1.20x1.40mm_HandSolder
R9, R19: 22.1k; R_0805_2012Metric_Pad1.20x1.40mm_HandSolder
R10, R20: 47.5k; R_0805_2012Metric_Pad1.20x1.40mm_HandSolder
R13, R23: 0R; R_0805_2012Metric_Pad1.20x1.40mm_HandSolder
R27: 220R; R_0805_2012Metric_Pad1.20x1.40mm_HandSolder
R28: 220k; R_0805_2012Metric_Pad1.20x1.40mm_HandSolder
R36: 27R; R_0805_2012Metric_Pad1.20x1.40mm_HandSolder
RN1, RN2, RN3, RN4: CAY16-301J4LF; RESCAF80P320X160X60-8N
SW1, SW3, SW4, SW5: B3F-1020; SW_B3F-1000_OMR
SW2: Water Level; PinHeader_1x02_P2.54mm_Vertical
TH1: 10k @ 25 C; SM_USS-M
U1: AZ1084CD-3.3TRG1; TO-252-3_6P6X6P1_DIO-M
U2, U3: SoilProbe1; PinHeader_1x01_P2.54mm_Vertical
U4, U6: CP2102N-A02-GQFN28R; CP2102-28__IC_CP2102N-A02-GQFN28R
U5: ESP32-WROOM-32E-N8; ESP32­WROOM­32E_EXP
U7: SN74ACT244DWR; DW20-M
U8, U9: SN74HCS595PWR; TSSOP16_PW_TEX-M
U10, U11: SoilMoistureProbe

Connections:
+3.3V: C2.1, C3.2, C4.1, C5.2, C6.1, C9.2, C10.1, C12.1, C14.1, C15.1, C18.1, C19.1, IC1.6 (VDD_1), IC1.15 (AVDD), IC1.22 (VDD_2), IC1.26 (VDD_3), IC1.43 (VDD_4), J2.5, J4.1, J4.3, J4.5, J4.7, J4.9, J4.11, J8.1, Q1.3 (D), R1.1, R3.2, R4.1, R11.1, R14.1, R16.1, R17.1, R18.1, R21.1, R24.2, R25.1, R26.1, R31.2, R36.2, SW2.1, SW5.1, U1.2 (OUTPUT), U4.6 (VDD), U4.7 (VREGIN), U5.2 (3V3), U6.6 (VDD), U6.7 (VREGIN)
+5V: C7.1, C8.1, C20.1, C21.1, C22.1, C23.1, D6.1 (K), J3.1, J3.3, J3.5, J3.7, J3.9, J3.11, J5.1, M1.1 (+), R15.2, R29.2, U1.3 (INPUT), U7.20 (VCC), U8.16 (VCC), U9.16 (VCC)
/Pump/Pump: IC1.33 (AN14_/_RPC10_/_RC10), R27.1
/Sensors/SoilActivate: IC1.24 (TDI_/_FLT15_/_RPB4_/_SCL2_/_RB4), Q1.1 (G)
/Sensors/SoilMoisture: IC1.25 (AN13_/_RPA4_/_T1G_/_RA4), J6.2, R5.1, U3.1
/Sensors/Temp: IC1.23 (DAC1/_AN12_/_RPA8_/_SDA2_/_RA8), J6.1, R4.2, TH1.1
/Sensors/WaterLevel: IC1.30 (RPD8_/_RD8), J6.3, R6.1, SW2.2
/USB_Output/RX_Output: IC1.18 (OA3IN-_/_AN7_/_C3IN1-_/_RPC1_/_RC1), J12.2, U6.26 (TXD)
/USB_Output/TX_Output: IC1.9 (OA2OUT_/_AN0_/_C2IN2-_/_RPA0_/_RA0), J12.1, U6.25 (RXD)
/UserIO/SCK: IC1.1 (RPA7_/_PWML4_/_RA7), J13.1, U7.2 (1A1)
/UserIO/SDO: IC1.3 (RPB15_/_PWML1_/_RB15), J13.3, U7.6 (1A3)
/UserIO/SS: IC1.2 (RPB14_/_PWMH1_/_RB14), J13.2, U7.4 (1A2)
/UserIO/SetLevel1: IC1.37 (TMS_/_AN16_/_LVDIN_/_RPB9_/_RB9), Q6.1 (G)
/UserIO/SetLevel2: IC1.38 (RPC6_/_RC6), Q8.1 (G)
/UserIO/UserButton: IC1.8 (AN10_/_C2IN4-_/_RPA11_/_FLT14_/_RA11), R30.2, SW5.4
/UserIO/WaterLow: IC1.7 (AN11_/_C1IN4-_/_RPA12_/_FLT13_/_RA12), Q13.1 (G)
/WiFi/CS1: IC1.32 (PGC2/RPB6_/_SCL1_/_RB6), J1.2, U5.29 (IO5)
/WiFi/MISO: IC1.39 (RPC7_/_RC7), J1.4, U5.31 (IO19)
/WiFi/MOSI: IC1.31 (PGD2/_RPB5_/_SDA1_/_RB5), J1.3, U5.37 (IO23)
/WiFi/SCK1: IC1.34 (AN15_/_RPB7_/_SCK1_/_INT0_/_RB7), J1.1, U5.30 (IO18)
GND: C1.2, C2.2, C3.1, C4.2, C5.1, C6.2, C7.2, C8.2, C9.1, C10.2, C11.1, C12.2, C13.2, C14.2, C15.2, C16.2, C17.2, C18.2, C19.2, C20.2, C21.2, C22.2, C23.2, CR1.1, CR2.1, D1.1 (K), D7.13, D7.14, IC1.5 (VSS_1), IC1.16 (AVSS), IC1.21 (VSS_2), IC1.29 (VSS_3), IC1.42 (VSS_4), J2.4, J3.2, J3.4, J3.6, J3.8, J3.10, J3.12, J4.2, J4.4, J4.6, J4.8, J4.10, J4.12, J5.2, J7.5 (GND), J8.3, J8.5, J9.5 (GND), Q4.2 (S), Q6.2 (S), Q8.2 (S), Q13.2 (S), R5.2, R6.2, R10.1, R13.2, R20.1, R23.2, R28.2, R30.1, SW1.1, SW3.4, SW4.1, TH1.2, U1.1 (ADJ/GND), U4.3 (GND), U4.29 (EXP), U5.1 (GND), U5.15 (GND), U5.38 (GND), U5.39 (GND), U5.40 (GND), U5.41 (GND), U5.42 (GND), U5.43 (GND), U5.44 (GND), U5.45 (GND), U5.46 (GND), U5.47 (GND), U6.3 (GND), U6.29 (EXP), U7.1 (*1OE), U7.10 (GND), U7.19 (*2OE), U8.8 (GND), U8.13 (*OE), U9.8 (GND), U9.13 (*OE)
unnamed: C1.1, R1.2, R2.1, SW1.4
unnamed: D1.2 (A), R3.1
unnamed: D2.2 (A), R16.2
unnamed: D2.1 (K), U4.19 (GPIO0_TXT)
unnamed: D3.2 (A), R17.2
unnamed: D3.1 (K), U4.18 (GPIO1_RXT)
unnamed: D4.2 (A), R25.2
unnamed: D4.1 (K), U6.19 (GPIO0_TXT)
unnamed: D5.2 (A), R26.2
unnamed: D5.1 (K), U6.18 (GPIO1_RXT)
unnamed: D6.2 (A), M1.2 (-), Q4.3 (D)
unnamed: D7.1, RN2.1
unnamed: D7.2, RN1.4
unnamed: D7.3, RN1.3
unnamed: D7.4, RN2.4
unnamed: D7.5, RN4.1
unnamed: D7.6, RN3.4
unnamed: D7.7, RN4.3
unnamed: D7.8, RN3.3
unnamed: D7.9, RN4.4
unnamed: D7.10, RN3.2
unnamed: D7.11, RN3.1
unnamed: D7.12, RN4.2
unnamed: D7.15, RN1.2
unnamed: D7.16, RN1.1
unnamed: D7.17, RN2.3
unnamed: D7.18, RN2.2
unnamed: D8.2 (A), R24.1
unnamed: D8.1 (K), Q6.3 (D)
unnamed: D10.2 (A), R31.1
unnamed: D10.1 (K), Q8.3 (D)
unnamed: D15.2 (A), R36.1
unnamed: D15.1 (K), Q13.3 (D)
unnamed: IC1.13 (PGC1/OA1IN+_/_AN4_/_C1IN1+_/_C1IN3-_/_R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), J2.2
unnamed: IC1.14 (PGD1/OA1IN-_/_AN5_/_CTCMP_/_C1IN1-_/_RT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), J2.3
unnamed: IC1.48 (PWMH4_/_RA10), J10.5
unnamed: IC1.46 (RPB12_/_PWMH2_/_RB12), J10.3
unnamed: IC1.47 (RPB13_/_PWML2_/_CTPLS_/_RB13), J10.4
unnamed: IC1.45 (TCK_/_RPB11_/_PWML3_/_RB11), J10.2
unnamed: IC1.44 (TDO_/_RPB10_/_PWMH3_/_RB10), J10.1
unnamed: IC1.4 (~MCLR), J2.6, R2.2
unnamed: CR1.4, J7.3 (D+), U4.4 (D+)
unnamed: CR1.3, J7.2 (D-), U4.5 (D-)
unnamed: CR1.2, J7.1 (VBUS), R9.1
unnamed: CR2.4, J9.3 (D+), U6.4 (D+)
unnamed: CR2.3, J9.2 (D-), U6.5 (D-)
unnamed: CR2.2, J9.1 (VBUS), R19.1
unnamed: J11.1, U5.28 (IO17)
unnamed: J11.2, U5.27 (IO16)
unnamed: J11.3, U5.26 (IO4)
unnamed: Q1.2 (S), U2.1
unnamed: Q2.1, R8.2
unnamed: Q3.1, R7.2
unnamed: Q4.1 (G), R27.2, R28.1
unnamed: R12.2, R13.1
unnamed: R22.2, R23.1
unnamed: R12.1, U4.23 (CTS)
unnamed: Q2.2, R7.1, U4.28 (DTR)
unnamed: Q3.2, R8.1, U4.24 (RTS)
unnamed: U4.25 (RXD), U5.35 (TXD0)
unnamed: U4.26 (TXD), U5.34 (RXD0)
unnamed: R9.2, R10.2, U4.8 (VBUS)
unnamed: R11.2, U4.9 (~RST)
unnamed: C11.2, C13.1, J8.10, Q3.3, R14.2, SW3.1, U5.3 (EN)
unnamed: C16.1, C17.1, Q2.3, R18.2, SW4.4, U5.25 (IO0)
unnamed: J8.8, U5.14 (IO12)
unnamed: J8.4, U5.16 (IO13)
unnamed: J8.2, U5.13 (IO14)
unnamed: J8.6, U5.23 (IO15)
unnamed: R22.1, U6.23 (CTS)
unnamed: R19.2, R20.2, U6.8 (VBUS)
unnamed: R21.2, U6.9 (~RST)
unnamed: U7.18 (1Y1), U8.11 (SRCLK), U9.11 (SRCLK)
unnamed: U7.16 (1Y2), U8.12 (RCLK), U9.12 (RCLK)
unnamed: U7.14 (1Y3), U8.14 (SER)
unnamed: R15.1, U8.10 (*SRCLR)
unnamed: RN1.8, U8.15 (QA)
unnamed: RN1.7, U8.1 (QB)
unnamed: RN1.6, U8.2 (QC)
unnamed: RN1.5, U8.3 (QD)
unnamed: RN2.8, U8.4 (QE)
unnamed: RN2.7, U8.5 (QF)
unnamed: RN2.6, U8.6 (QG)
unnamed: U8.9 (QH'), U9.14 (SER)
unnamed: RN2.5, U8.7 (QH)
unnamed: R29.1, U9.10 (*SRCLR)
unnamed: RN3.8, U9.15 (QA)
unnamed: RN3.7, U9.1 (QB)
unnamed: RN3.6, U9.2 (QC)
unnamed: RN3.5, U9.3 (QD)
unnamed: RN4.8, U9.4 (QE)
unnamed: RN4.7, U9.5 (QF)
unnamed: RN4.6, U9.6 (QG)
unnamed: RN4.5, U9.7 (QH)
unnamed: U10.2, U10.3, U10.4
unnamed: U11.2, U11.3, U11.4

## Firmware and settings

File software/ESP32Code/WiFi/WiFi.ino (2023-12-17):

#include <WiFi.h>
#include <WebServer.h>
#include <SPI.h>
#include <ESP32SPISlave.h>
#include "SmartPotHTML.h"   // .h file that stores html code

#define ROOM058_WIFI

#ifdef ROOM058_WIFI
/* Network Details */
const char* ssid = "EE-IoT";  // Enter SSID here
const char* password = " 350Serra";  //Enter Password here
#endif



// the XML array size needs to be bigger that your maximum expected size
char XML[2048];

// just some buffer holder for char operations
char buf[32];

// variable for the IP reported once connected to LAN
IPAddress Actual_IP;

// Create the webserver
WebServer server(80);

// Create the SPI Slave
ESP32SPISlave spi_slave;

static constexpr uint32_t BUFFER_SIZE {6};
uint8_t spi_slave_tx_buf[BUFFER_SIZE];
uint8_t spi_slave_rx_buf[BUFFER_SIZE];

bool Unit_Select = false;
bool Unit_Val = false;
bool Threshold_Select = false;
bool Threshold_Val = false;
bool Water_Press = false;

uint8_t current_temp = 0;
uint8_t current_soil_moisture = 0;
bool unit_change = false;
uint8_t unit_change_status = 0;
bool threshold_change = false;
uint8_t threshold_change_status = 0;
uint8_t water_change_status = 0;
uint8_t received_data = 0;
/********************************************************************
setup()

The setup code for the ESP32, runs once at startup

Parameters: None

Returns: None

********************************************************************/
void setup() {

  // Get UART started to communicate with computer
  Serial.begin(115200);
  delay(1000);

  Serial.println("Connecting to ");
  Serial.println(ssid);

  //connect to your local wi-fi network
  WiFi.begin(ssid, password);

  //check wi-fi is connected to wi-fi network
  while (WiFi.status() != WL_CONNECTED) {
  delay(1000);
  Serial.print(".");
  }
  Serial.println("");
  Serial.println("WiFi connected..!");
  Serial.print("Got IP: ");  Serial.println(WiFi.localIP());

  // if  web page or XML are large, may not get a call back from the web page
  // and the ESP32 will think something has locked up and reboot the ESP
  // disable watch dog timer 0 so this doesn't happen
  disableCore0WDT();

  // disable watch dog timer 1 as well
  disableCore1WDT();

  // Serial Update
  Serial.println("starting server");

  // Connect to the LAN
  WiFi.begin(ssid, password);
  while (WiFi.status() != WL_CONNECTED) {
    delay(500);
    Serial.print(".");
  }
  Serial.print("IP address: "); Serial.println(WiFi.localIP());
  Actual_IP = WiFi.localIP(); // Save the assigned IP address

  printWifiStatus();

  // these calls will handle data coming back from your web page
  // this one is a page request, upon ESP getting / string the web page will be sent
  server.on("/", SendWebsite);

  // upon esp getting /XML string, ESP will build and send the XML, this is how we refresh
  // just parts of the web page
  server.on("/xml", SendXML);

  // upon ESP getting /BUTTON_0 string, ESP will execute the ProcessButton_0 function, etc.
  // Need some javascript in the web page to send these strings
  // this process is documented in SmartPotHTML.h
  server.on("/FAHRENHEIT_BUTTON", ProcessFahrenheitButton);
  server.on("/CELSIUS_BUTTON", ProcessCelsiusButton);
  server.on("/LOW_THRESHOLD_BUTTON", ProcessLowThresholdButton);
  server.on("/HIGH_THRESHOLD_BUTTON", ProcessHighThresholdButton);
  server.on("/WATER_BUTTON", ProcessWaterButton);

  // finally begin the server
  server.begin();


  // Set up the SPI
  spi_slave.setDataMode(SPI_MODE0);
  spi_slave.begin(VSPI); // Use VSPI, Default should be CS:  5, CLK: 18, MOSI: 23, MISO: 19

  // clear buffers
  memset(spi_slave_tx_buf, 0, BUFFER_SIZE);
  memset(spi_slave_rx_buf, 0, BUFFER_SIZE);

}

/********************************************************************
loop()

The main loop of the code, handles sending data via the web server

Parameters: None

Returns: None

********************************************************************/
void loop() {
 
  // Everytime we receive an update via SPI we process it and and send to server
  // block until the transaction comes from master
    spi_slave.wait(spi_slave_rx_buf, spi_slave_tx_buf, BUFFER_SIZE);

    // if transaction has completed from master,
    // available() returns the number of completed transactions,
    // and `spi_slave_rx_buf` is automatically updated
    while (spi_slave.available()) {
        // do something with `spi_slave_rx_buf`
        // Serial.print("Command Received: ");
        // Serial.println(spi_slave_rx_buf[0]);
        // Serial.println(spi_slave_rx_buf[1]);

        // received_data = spi_slave_rx_buf[0];
        // current_temp = received_data;

        uint8_t buf0 = spi_slave_rx_buf[0];
        uint8_t buf1 = spi_slave_rx_buf[1];
        uint8_t buf2 = spi_slave_rx_buf[2];
        uint8_t buf3 = spi_slave_rx_buf[3];
        uint8_t buf4 = spi_slave_rx_buf[4];
        uint8_t buf5 = spi_slave_rx_buf[5];

        if ((buf0 == buf3) && buf0 > 0) {
          current_temp = buf0;
          Serial.print("Updated Temp: ");
          Serial.println(buf0);
        }

        if ((buf1 == buf4) && buf1 > 0) {
          current_soil_moisture = buf1;
          Serial.print("Updated Soil Moisture: ");
          Serial.println(buf1);
        }

        if ((buf2 == buf5) && buf2) {
          if (0b00000001 & buf2) {
            Serial.println("Threshold Update");
            threshold_change = true;
            threshold_change_status = ((0b00000010 & buf2) > 0)+1;
          }

          if (0b10000000 & buf2) {
            Serial.println("Unit Update");
            unit_change = true;
            if (0b01000000 & buf2) {
              unit_change_status = 2;
            } else {
              unit_change_status = 1;
            }
          } else {
            unit_change_status = 0;
          }

          // if (0b00100000 & buf2) {
          //   if (0b00010000 & buf2) {
          //     water_change_status = 2;
          //   } else {
          //     water_change_status = 1;
          //   }
          // } else {
          //   water_change_status = 0;
          // }

        }

        // for (size_t i=0; i < BUFFER_SIZE; ++i) {
        //   printf("%d ", spi_slave_rx_buf[i]);
        // }
        // printf("\n");
        // if (received_data >= 128) {
        //   current_temp = received_data - 128;
        // } else {
        //   if (0b00000010 | received_data) {
        //     unit_change = true;
        //     unit_change_status = 0b00000001 | received_data + 1;
        //   } else if (0b00001000 | received_data) {
        //     threshold_change = true;
        //     threshold_change_status = (0b00000100 | received_data)/4 + 1;
        //   }
        // }
        
        spi_slave.pop();
    }
  
  // Must call handleClient to give webpage instructions to do something
  server.handleClient();

  // Update the data to transmit to the master
  spi_slave_tx_buf[0] = 0b10000000;

  if (Unit_Select) {
    spi_slave_tx_buf[0] = spi_slave_tx_buf[0] | 0b10000010; // Set bit 2 high to indicate unit update
    if (Unit_Val){
      spi_slave_tx_buf[0] = spi_slave_tx_buf[0] | 0b10000001; // Set bit 1 high to indicate Fahrenheit, otherwise celsius
    }
    Unit_Select = false; // Don't want to continuously send unit updates
  }

  if (Threshold_Select) {
    // spi_slave_tx_buf[0] = spi_slave_tx_buf[0] | 0b10000010; // Set bit 2 high to indicate High Threshold
    spi_slave_tx_buf[0] = spi_slave_tx_buf[0] | 0b10010000; // Set bit 5 high to indicate unit update
    if (Threshold_Val){
      spi_slave_tx_buf[0] = spi_slave_tx_buf[0] | 0b10011000; // Set bit 4 high to indicate High threshold, otherwise low threshold
    }
    Threshold_Select = false; // Don't want to continuously send threshold updates
    Serial.print("Threshold Signal: ");
    Serial.print(spi_slave_tx_buf[0]);
  }

  if (Water_Press) {
    spi_slave_tx_buf[0] = spi_slave_tx_buf[0] | 0b10000100; // Set bit 3 high to indicate we should water
    Water_Press = false; // Don't want to continuously send water presses
  }
  
  // TODO: Send buf[1] to provide reliability
}


// Sends the main webpage
// PAGE_MAIN is a large char defined in SmartPotHTML.h
void SendWebsite() {
  Serial.println("sending web page");
  
  server.send(200, "text/html", PAGE_MAIN); // May need larger than 200 if page is large
}

// Sends the XML
// I avoid string data types at all cost hence all the char mainipulation code
void SendXML() {

  // Serial.println("sending xml");

  strcpy(XML, "<?xml version = '1.0'?>\n<Data>\n");

  // send Temp info
  sprintf(buf, "<TEMP>%d</TEMP>\n", current_temp);
  strcat(XML, buf);

  // send Soil info
  sprintf(buf, "<SOIL>%d</SOIL>\n", current_soil_moisture);
  strcat(XML, buf);

  sprintf(buf, "<Unit>%d</Unit>\n", unit_change_status);
  strcat(XML, buf);
  unit_change_status = 0;

  // sprintf(buf, "<low_water>%d</low_water>\n", water_change_status);
  // strcat(XML, buf);
  // water_change_status = 0;
  
  if (threshold_change) {
    sprintf(buf, "<Water_Level>%d</Water_Level>\n", threshold_change_status);
    strcat(XML, buf);
    threshold_change = false;
  } else {
    strcat(XML, "<Water_Level>0</Water_Level>\n");
  }

  strcat(XML, "</Data>\n");

  // For debuggging, May need to increase size of XML[] if too large
  // Serial.println(XML);

  // Send the data
  server.send(200, "text/xml", XML); // May need larger than 200 if data is large
}

// Process what happens when the fahrenheit button is pressed
void ProcessFahrenheitButton() {

  // Edit SPI message to the PIC32
  Serial.println("Fahrenheit Button Pressed");
  Unit_Select = true;
  Unit_Val = true;

  // keep page live but dont send any thing
  server.send(200, "text/plain", ""); // Send web page
}

// Process what happens when celsius button is pressed
void ProcessCelsiusButton() {

  // Edit SPI message to the PIC32
  Serial.println("Celsius Button Pressed");
  Unit_Select = true;
  Unit_Val = false;

  // keep page live but dont send any thing
  server.send(200, "text/plain", ""); // Send web page
}

// Process what happens when the low threshold button is pressed
void ProcessLowThresholdButton() {

  // Edit SPI message to the PIC32
  Serial.println("Low Threshold Button Pressed");
  Threshold_Select = true;
  Threshold_Val = false;

  // keep page live but dont send any thing
  server.send(200, "text/plain", ""); // Send web page
}

// Process what happens when the high threshold button is pressed
void ProcessHighThresholdButton() {

  // Edit SPI message to the PIC32
  Serial.println("High Threshold Button Pressed");
  Threshold_Select = true;
  Threshold_Val = true;

  // keep page live but dont send any thing
  server.send(200, "text/plain", ""); // Send web page
}

// Process what happens when the water button is pressed
void ProcessWaterButton() {

  // Edit SPI message to the PIC32
  Serial.println("Water Button Pressed");
  Water_Press = true;

  // keep page live but dont send any thing
  server.send(200, "text/plain", ""); // Send web page
}

void printWifiStatus() {

  // print the SSID of the network you're attached to:
  Serial.print("SSID: ");
  Serial.println(WiFi.SSID());

  // print your WiFi shield's IP address:
  IPAddress ip = WiFi.localIP();
  Serial.print("IP Address: ");
  Serial.println(ip);

  // print the received signal strength:
  long rssi = WiFi.RSSI();
  Serial.print("signal strength (RSSI):");
  Serial.print(rssi);
  Serial.println(" dBm");
  // print where to go in a browser:
  Serial.print("Open http://");
  Serial.println(ip);
}

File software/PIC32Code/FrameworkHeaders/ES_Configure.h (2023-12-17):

/****************************************************************************
 Module
     ES_Configure.h
 Description
     This file contains macro definitions that are edited by the user to
     adapt the Events and Services framework to a particular application.
 Notes

 History
 When           Who     What/Why
 -------------- ---     --------
 12/19/16 20:19  jec     removed EVENT_CHECK_HEADER definition. This goes with
                         the V2.3 move to a single wrapper for event checking
                         headers
  10/11/15 18:00 jec     added new event type ES_SHORT_TIMEOUT
  10/21/13 20:54 jec     lots of added entries to bring the number of timers
                         and services up to 16 each
 08/06/13 14:10 jec      removed PostKeyFunc stuff since we are moving that
                         functionality out of the framework and putting it
                         explicitly into the event checking functions
 01/15/12 10:03 jec      started coding
*****************************************************************************/

#ifndef ES_CONFIGURE_H
#define ES_CONFIGURE_H

/****************************************************************************/
// The maximum number of services sets an upper bound on the number of
// services that the framework will handle. Reasonable values are 8 and 16
// corresponding to an 8-bit(uint8_t) and 16-bit(uint16_t) Ready variable size
#define MAX_NUM_SERVICES 16

/****************************************************************************/
// This macro determines that nuber of services that are *actually* used in
// a particular application. It will vary in value from 1 to MAX_NUM_SERVICES
#define NUM_SERVICES 8

/****************************************************************************/
// These are the definitions for Service 0, the lowest priority service.
// Every Events and Services application must have a Service 0. Further
// services are added in numeric sequence (1,2,3,...) with increasing
// priorities
// the header file with the public function prototypes
#define SERV_0_HEADER "UsbOutService.h"
// the name of the Init function
#define SERV_0_INIT InitUsbOutService
// the name of the run function
#define SERV_0_RUN RunUsbOutService
// How big should this services Queue be?
#define SERV_0_QUEUE_SIZE 5

/****************************************************************************/
// The following sections are used to define the parameters for each of the
// services. You only need to fill out as many as the number of services
// defined by NUM_SERVICES
/****************************************************************************/
// These are the definitions for Service 1
#if NUM_SERVICES > 1
// the header file with the public function prototypes
#define SERV_1_HEADER "TemperatureSM.h"
// the name of the Init function
#define SERV_1_INIT InitTemperatureSM
// the name of the run function
#define SERV_1_RUN RunTemperatureSM
// How big should this services Queue be?
#define SERV_1_QUEUE_SIZE 3
#endif

/****************************************************************************/
// These are the definitions for Service 2
#if NUM_SERVICES > 2
// the header file with the public function prototypes
#define SERV_2_HEADER "WiFiSM.h"
// the name of the Init function
#define SERV_2_INIT InitWiFiSM
// the name of the run function
#define SERV_2_RUN RunWiFiSM
// How big should this services Queue be?
#define SERV_2_QUEUE_SIZE 3
#endif

/****************************************************************************/
// These are the definitions for Service 3
#if NUM_SERVICES > 3
// the header file with the public function prototypes
#define SERV_3_HEADER "PumpSM.h"
// the name of the Init function
#define SERV_3_INIT InitPumpSM
// the name of the run function
#define SERV_3_RUN RunPumpSM
// How big should this services Queue be?
#define SERV_3_QUEUE_SIZE 3
#endif

/****************************************************************************/
// These are the definitions for Service 4
#if NUM_SERVICES > 4
// the header file with the public function prototypes
#define SERV_4_HEADER "DisplaySM.h"
// the name of the Init function
#define SERV_4_INIT InitDisplaySM
// the name of the run function
#define SERV_4_RUN RunDisplaySM
// How big should this services Queue be?
#define SERV_4_QUEUE_SIZE 3
#endif

/****************************************************************************/
// These are the definitions for Service 5
#if NUM_SERVICES > 5
// the header file with the public function prototypes
#define SERV_5_HEADER "UserButtonSM.h"
// the name of the Init function
#define SERV_5_INIT InitUserButtonSM
// the name of the run function
#define SERV_5_RUN RunUserButtonSM
// How big should this services Queue be?
#define SERV_5_QUEUE_SIZE 3
#endif
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

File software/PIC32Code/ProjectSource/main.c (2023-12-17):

/****************************************************************************
 Module
     main.c
 Description
     starter main() function for Events and Services Framework applications
 Notes

*****************************************************************************/
#include <stdint.h>
#include <stdbool.h>
#include <stdio.h>
#include <assert.h>

#include "ES_Configure.h"
#include "ES_Framework.h"
#include "ES_Port.h"


void main(void)
{
  ES_Return_t ErrorType = Success;

  _HW_PIC32Init(); // basic PIC hardware init
  // Your hardware initialization function calls go here
  
  // now initialize the Events and Services Framework and start it running
  ErrorType = ES_Initialize(ES_Timer_RATE_1mS);
  if (ErrorType == Success)
  {
    ErrorType = ES_Run();
  }
  //if we got to here, there was an error
  switch (ErrorType)
  {
    case FailedPost:
    {
      ErrorType = 0; // a hack to get a readable assert message
      assert( FailedPost == ErrorType );
      //DB_printf("Failed on attempt to Post\n");
    }
    break;
    case FailedPointer:
    {
      ErrorType = 0; // a hack to get a readable assert message
      assert( FailedPointer  == ErrorType );
//      DB_printf("Failed on NULL pointer\n");
    }
    break;
    case FailedInit:
    {
      ErrorType = 0; // a hack to get a readable assert message
      assert( FailedInit  == ErrorType );
//      DB_printf("Failed Initialization\n");
    }
    break;
    default:
    {
      ErrorType = 0; // a hack to get a readable assert message
      assert( FailedOther  == ErrorType );
//      DB_printf("Other Failure\n");
    }
    break;
  }
  for ( ; ;)
  {
    ;
  }
}
